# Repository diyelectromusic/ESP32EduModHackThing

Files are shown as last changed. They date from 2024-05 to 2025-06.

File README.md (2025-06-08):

# ESP32EduModHackThing

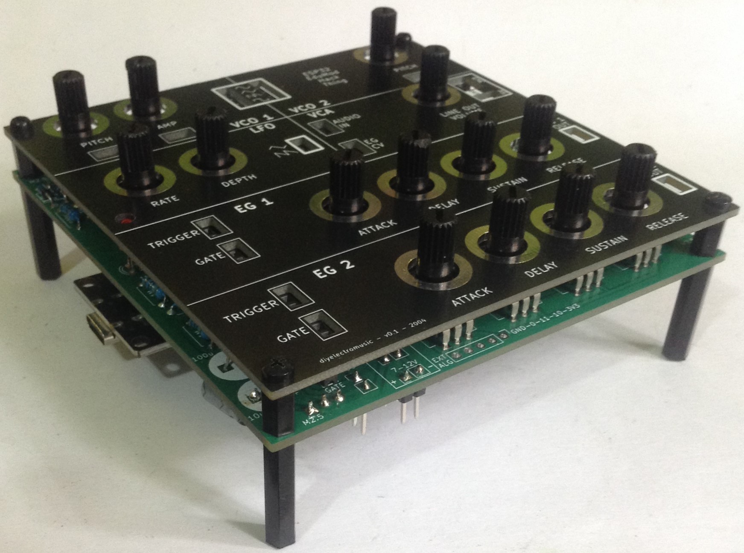
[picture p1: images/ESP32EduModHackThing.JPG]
Photo of the ESP32EduModHackThing


ESP32 based, hacked together modular-synth like thing to help learn the basics of analog synthesis and hook up to breadboards for experimenting with circuits.

* Blog series: https://diyelectromusic.wordpress.com/2024/05/07/educational-diy-synth-thing/

## Getting Started

Once the hardware is ready (see below) here are some links to get started:
* One-sheet Getting Started Guide: [Download Here](Docs/EduModSynthThing-GettingStarted.pdf).
* Some first experiments: https://diyelectromusic.com/2024/06/17/educational-diy-synth-thing-part-5/
* Tutorials: [See Docs area](Docs/)

## Hardware

**Be sure to read the Errata and limitations in the design notes**

Contents of the [Hardware](/Hardware) directory:
* Main PCB - 100x100mm main PCB.
* 24pin DIP Adaptor - small adaptor PCB as a workaround to the errata about the 24-pin DIP socket.
* Front Panel - 100x100mm PCB files that can be used as a front panel.

Note: The above does not include any connections for MIDI, audio, or power.  See the build notes for details.

Additional hardware (optional):
* Connector Panel - 50x100mm PCB files that can be used as an additional accessories/connectors panel.
* 3D Printer STL file - 150x100x35mm approx enclosure for a front panel and connector panel.
* 3D Printer STL file for a low quality tool to help screw in the hex-spacers.
* Alternative Connector Panel - 50x100mm PCB files for accessories/connectors including a JST SH 4-way header for power and MIDI compatible with my Raspberry Pi Pico Touch Keyboard.
* JST SH 4-pin breakout board - breakout board for use with the alternative connecor panel.

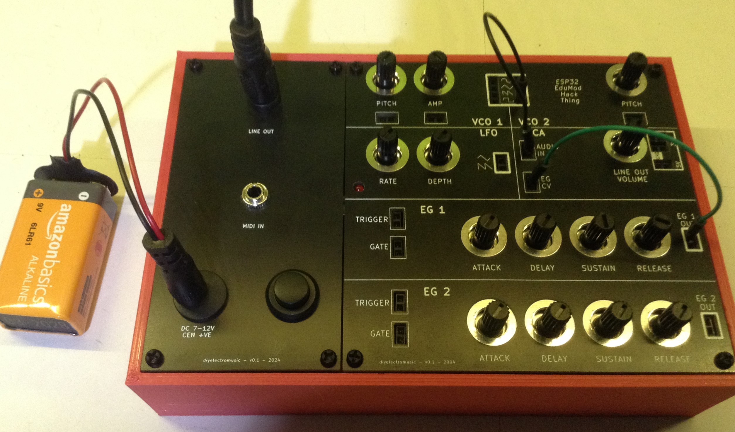
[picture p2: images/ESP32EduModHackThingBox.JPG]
Photo of the ESP32EduModHackThing in its box


Main PCB:
* PCB Design Notes: https://diyelectromusic.wordpress.com/2024/05/07/esp32-wroom-educational-modular-synth-thing-pcb-design/
* PCB Build and Test Notes: https://diyelectromusic.wordpress.com/2024/05/19/esp32-wroom-educational-modular-synth-thing-pcb-design-build-guide/

## Code Directories

* HardwareTestCode - contains a series of sketches that can be used to test specific elements of the board.
* Firmware - contains the current release of the core firmware to perform all the functionss as described in the blog series.

## License, Use, Feedback, Contributions

Released under a MIT license.  No fitness for any purpose suggested or implied.  Use at your own risk.  I am not an electronics person - I'm just messing around.

**Do not plug this into anything else and certainly not anything expensive or wanted.**

Contributions are not being accepted.  This is just a repository for the design, but suggestions and conversations about it welcome on my blog or via social media.

Kevin

_All code and designs Copyright (c) Kevin (diyelectromusic)_

There is no permission, direct or implied, for the contents of this repository to be used for the training of AI systems.

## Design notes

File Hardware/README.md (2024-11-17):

# ESP32EduModHackThing

* Blog series: https://diyelectromusic.wordpress.com/2024/05/07/educational-diy-synth-thing/
* PCB Design Notes: https://diyelectromusic.wordpress.com/2024/05/07/esp32-wroom-educational-modular-synth-thing-pcb-design/
* PCB Build and Test Notes: https://diyelectromusic.wordpress.com/2024/05/19/esp32-wroom-educational-modular-synth-thing-pcb-design-build-guide/

Bill of Materials:
- ESP32 WROOM Educational Modular Synth Thing PCB.
- 24-pin DIP adaptor PCB (see note on footprint error below).
- ESP32 WROOM DevKit.
- 1 x CD4067B 24-pin DIP 16-way analog multiplexer (see note below on footprint error!).
- 1x H11L1 6-pin DIP opto-isolator.
- 1x TDA7052A 8-pin DIP BTL audio amplifier with DC volume control.
- 1x L7805 TO-220 5V voltage regulator.
- Resistors: 1 x 220R, 11 x 470R, 5 x 1K, 4 x 10K, 5 x 100K, 3 x 680K, 6 x 1M, 1 x 2M
- Variable Resistors: 13 x 10K linear (PCB Mount: RK09 footprint), 1 x 100K linear (PCB Mount: RK09 footprint)
- 4 x 2N3904 NPN transistors
- 1 x BC557 PNP transistor
- 5 x 1N4148 signal diodes
- 6 x BAT43 Schottky diode
- 1 x 3mm LED
- Ceramic Capacitors: 10 x 68 nF, 7 x 100nF
- Electrolytic Capacitors: 2 x 1uF, 2 x 10uF, 1 x 100uF
- 15 x 2-way pin header sockets.
- 2 x 4-way pin header sockets.
- Jumper header pins.
- 2 x 15-way pin header sockets.
- Optional: 24-pin DIP socket (see note below on footprint error!).
- Optional: 8-pin DIP socket.
- Optional: 6-pin DIP socket.

Errata:
- The 24-pin DIP footprint is incorrect and requires an adaptor board.
- There is no board space to allow the two power supply electrolytics to bend over the PCB.
- The footprint for the 2N3904 transistors is too small for easy soldering.
- Using GPIO 2, 4, 15 as analog input values causes issues - see design notes for details.
- The panel uses "DELAY" rather than "DECAY" in the lables for the ADSR...

This repository also contains:
* 24-pin DIP narrow to wide adaptor.
* Front panel design.
* Connector panel design.
* Alternative connector panel "V2" design (includes a JST SH breakout).
* JST SH 4-pin breakout board.
* STL file for a 3D Printed box for both panels.
* STL file for a 3D Printed tool to help screw in spacers.

If you like what you see, you can buy me a Ko-Fi - https://ko-fi.com/diyelectromusic

#  A Word of Caution!

Please note - I consider myself a novice at pcb design!

**Don't spend your own time and resources on any of these designs without knowing what you are doing.  They are not "off the shelf products" ready to go!**

Do not use this with expensive computer, audio, music or electronic equipment, it is for hobby use only.  For more details, see https://diyelectromusic.wordpress.com/pcbs/

# License

All information is provided AS IS with no implied fit for purpose as detailed in the included MIT License.

All content and code (c) diyelectromusic (Kevin)

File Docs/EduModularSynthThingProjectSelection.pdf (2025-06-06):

# The Educational DIY Synth Thing

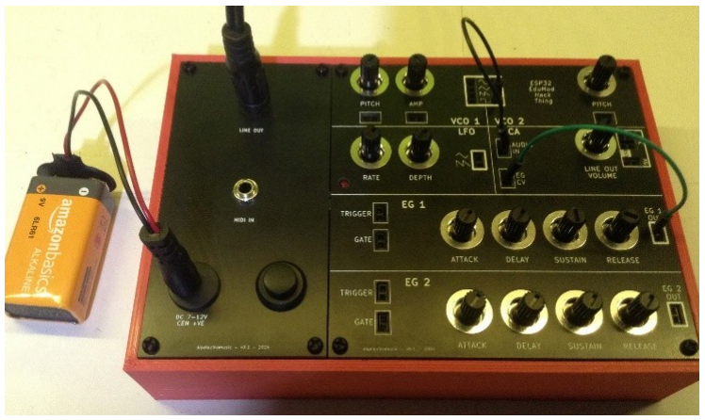
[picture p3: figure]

### Project Selection – v0.1 – June 2025 © diyelectromusic 2025

https://diyelectromusic.com/2024/05/07/educational-diy-synth-thing/ (https://diyelectromusic.com/2024/05/07/educational-diy-synth-thing/)

# 1. Basic Oscillator (VCO) Output

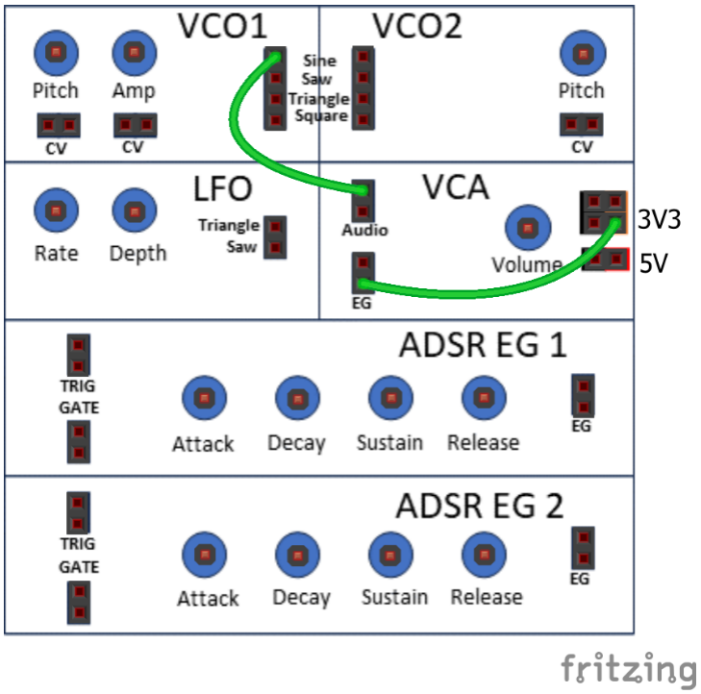
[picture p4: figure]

- VCA EG fixed at 3V3.
- Turn up VCA Volume.

## - Experiment with:

- VCO1 Amp.
- VCO1 Pitch.

## - What are the highest and lowest frequencies?

# 2. Dual Oscillator Output

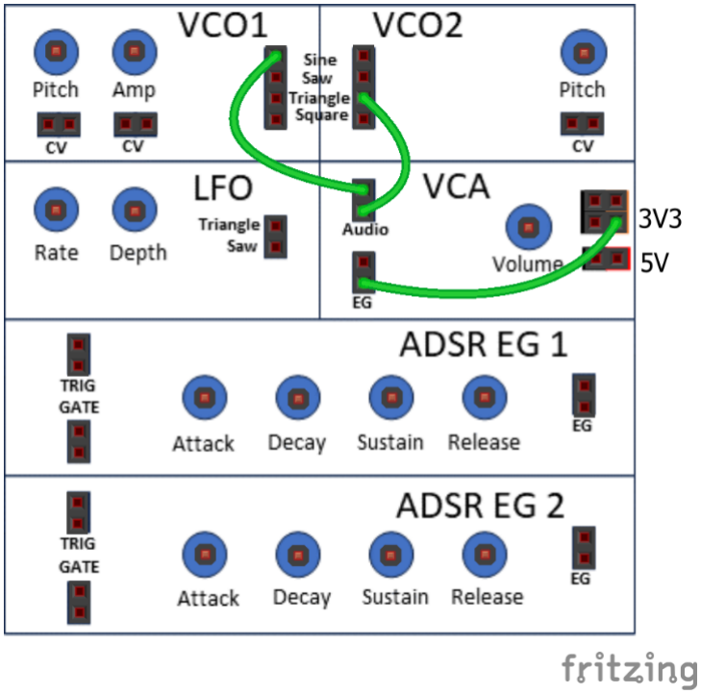
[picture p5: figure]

## - Change:

- VCO1 and VCO2 Pitch.
- VCO1 Amp.
- VCO1 and VCO2 Waveforms.

## - Experiments:

- Tune to same pitch.
- Detune one slightly.
- Tune to 1 octave apart.
- Tune to 2 octaves.
- Find other intervals.

# 3. Dual VCO+LFO Pitch Modulation

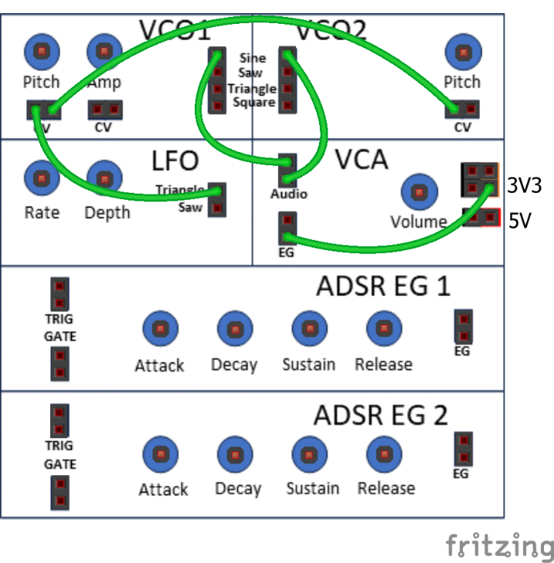
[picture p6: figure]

- Links VCO1 and VCO2 CVs.

## - Turn LFO off and tune VCOs to 1

octave.
- Try LFO Rate and Depth.
- Try LFO waveforms.

## - Connect one LFO waveform to

VCO1 and one to VCO2.

# 4. ADSR Envelope Generator for Amplitude and Pitch

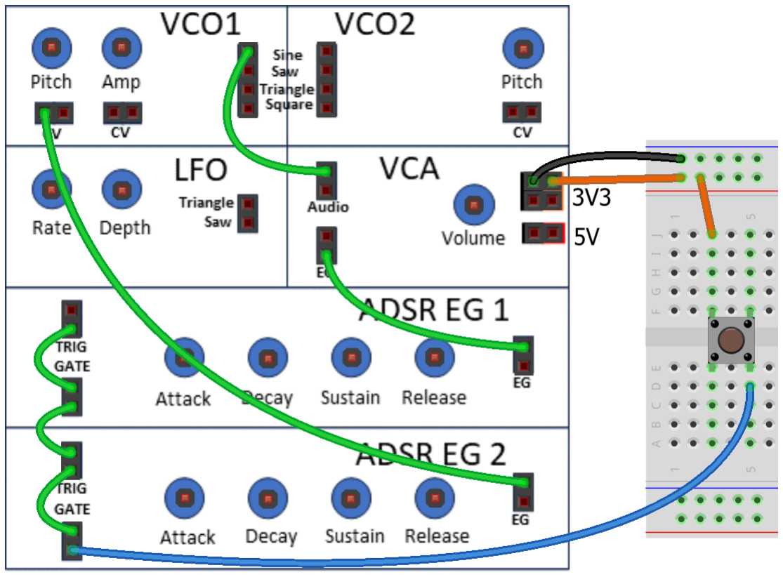
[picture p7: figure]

- EG1 back to controlling VCA.
- EG2 now controlling VCO Pitch.

## - Try different A, D, S, R settings for

both amplitude and pitch.

# 5. ADSR Envelope Generator – Dual Pitch

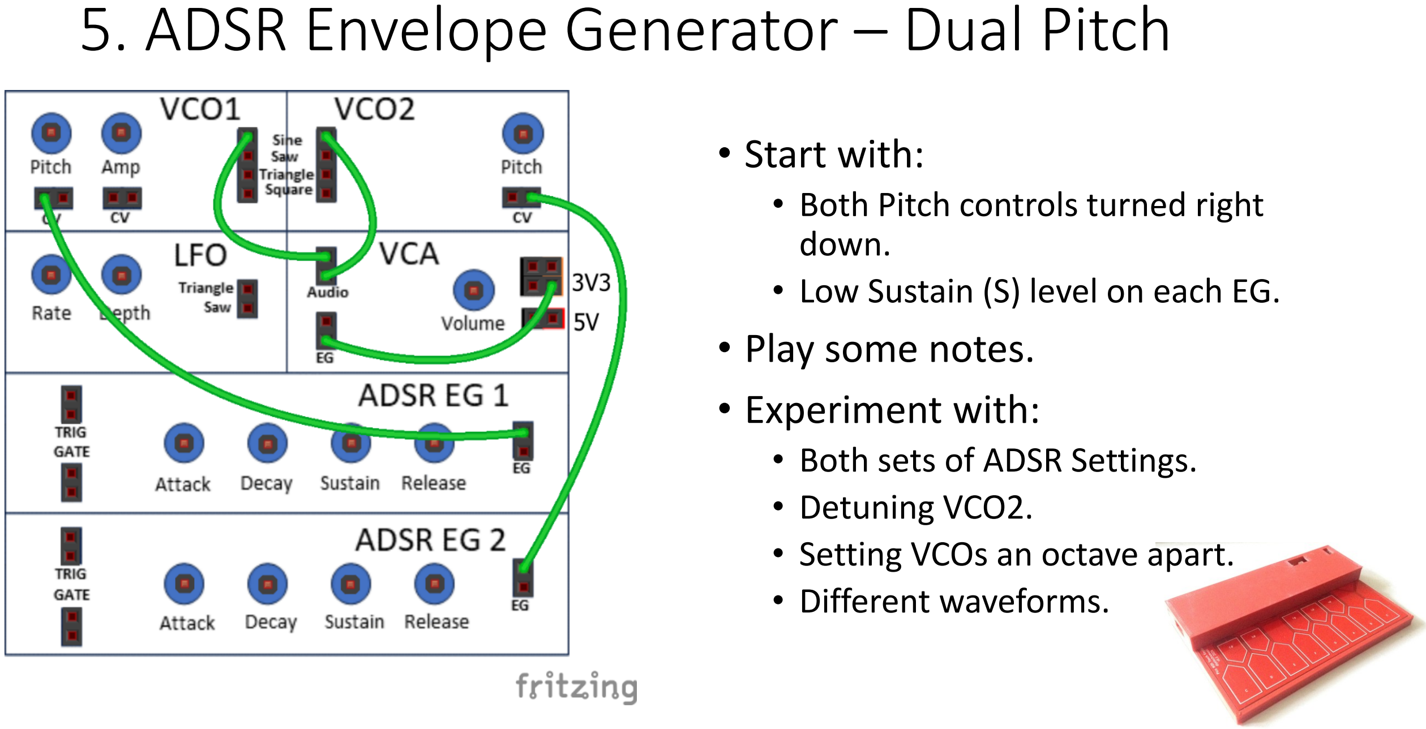
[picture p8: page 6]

## - Start with:

## - Both Pitch controls turned right

down.
- Low Sustain (S) level on each EG.
- Play some notes.

## - Experiment with:

- Both sets of ADSR Settings.
- Detuning VCO2.
- Setting VCOs an octave apart.
- Different waveforms.

# 6. Dual Pitch Sequence

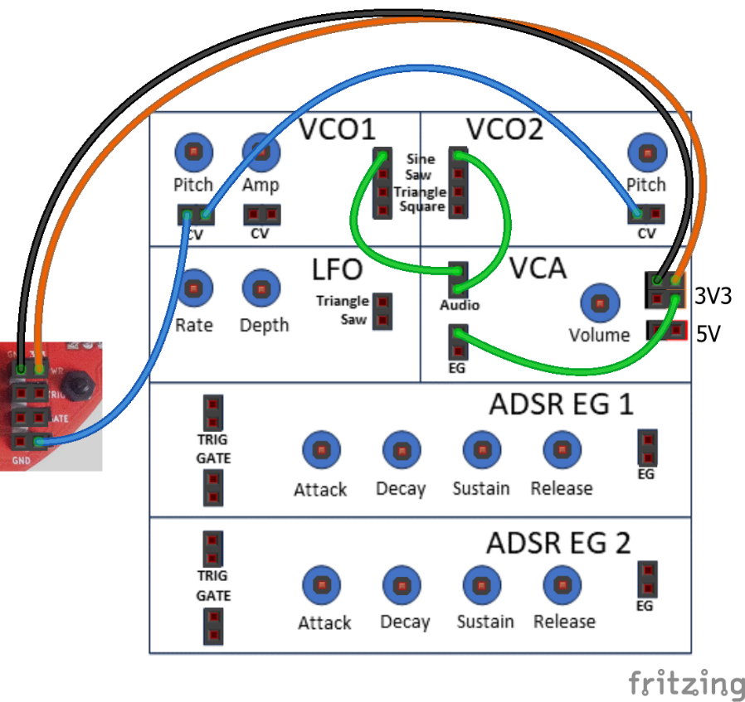
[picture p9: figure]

- Both VCOs connected.

## - Start with:

- VCO Pitch controls turned right down.
- VCO1 Amp and VCA Volume right up.
- Baby 8 steps fully clockwise (8 steps).
- Baby 8 Run/Stop -> Run (to the right).

## - Experiment with:

- Detune VCO2.
- Different Waveforms.
- Different Pitch controls.
- Adjust the sequence.

# 7. Dual Oscillators and Oscilloscope

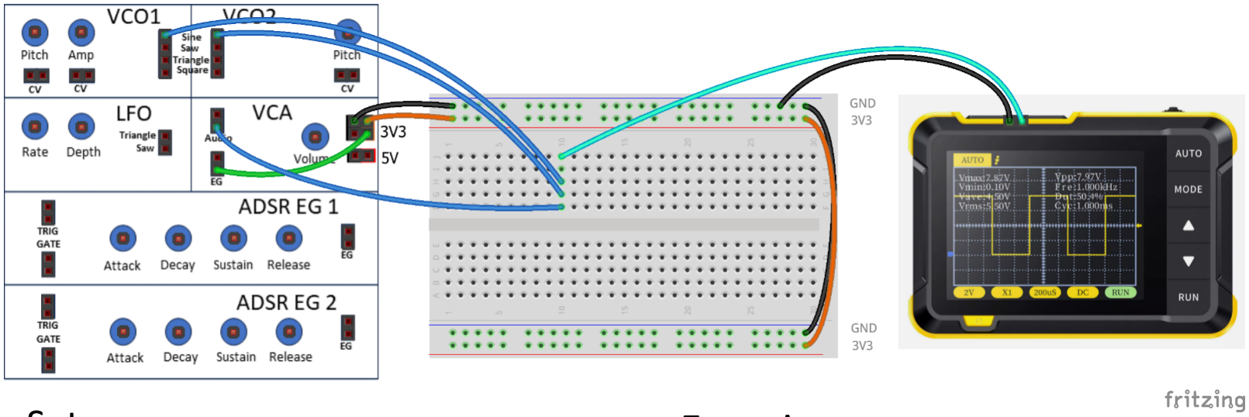
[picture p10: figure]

## Setup:

- VCA Amp turned fully clockwise.
- VCO1 Amp fully anticlockwise (off).
- VCO1 and VCO2 Pitch half-way.
- Use both Sine outputs.

## Experiment:

- Slowly increase VCO1 Amp.
- Tune both VCOs to same Pitch.
- Watch how the waveform slowly changes.

# 8. LED Indicator

## - Experiment with:

## - LFO Rate - LFO Depth - LFO Waveform

## - Contrast fast rate with

very slow rate.

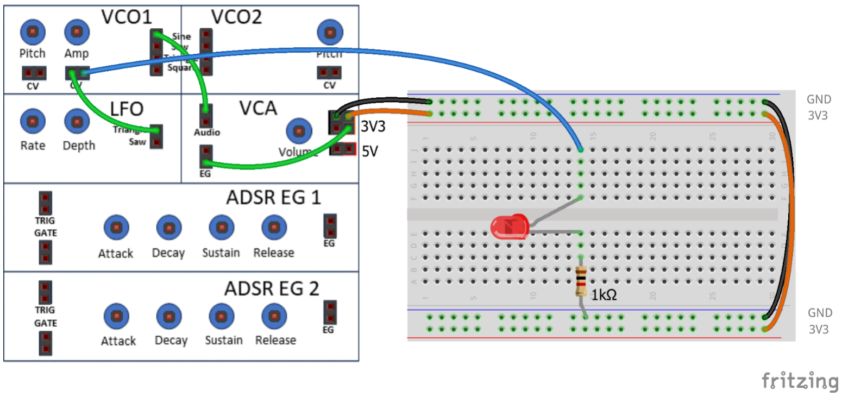
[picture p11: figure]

## Setup

- VCO1 Amp fully anti-clockwise (“off”).
- VCO1 Pitch half-way.
- LFO Depth half-way.
- LFO Rate fully anti-clockwise (“slow”).

# 9. Potentiometer Control

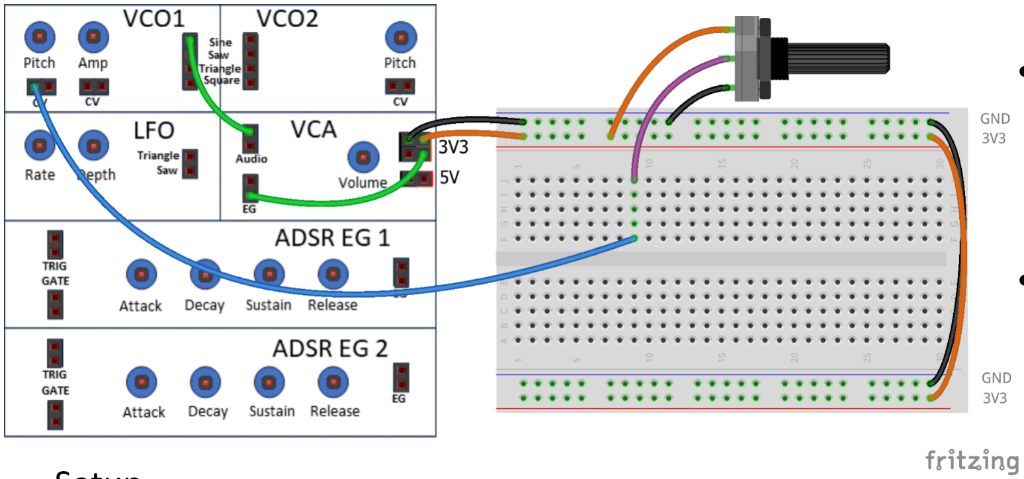
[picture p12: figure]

## - Experiment with:

## - VCO1 Pitch - Pot Control

## - Notice how the two add to each other…

## Setup

- Pot between 3V3 and GND.
- VCO1 Amp and VCA Vol fully clockwise.

# 10. Light Dependant Resistor Control

## - Move hand over the

LDR.

## - Experiment with different positions from fully covered to

fully open.

## - This simulates an instrument called a

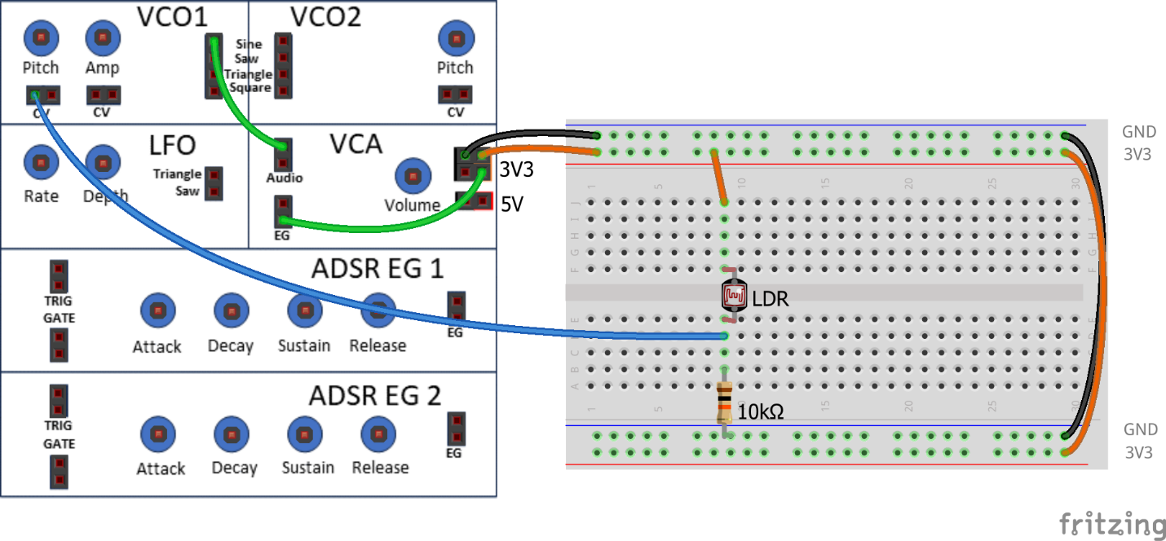
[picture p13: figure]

Setup | “Theremin”.
- VCO1 Pitch half-way.
- VCO1 Amp and VCA Vol fully clockwise.

# 11. Force Sensitive Resistor Control

## - Apply Pressure to the FSR…

## - Now acts as a “pitch bend” for the Synth

Thing.

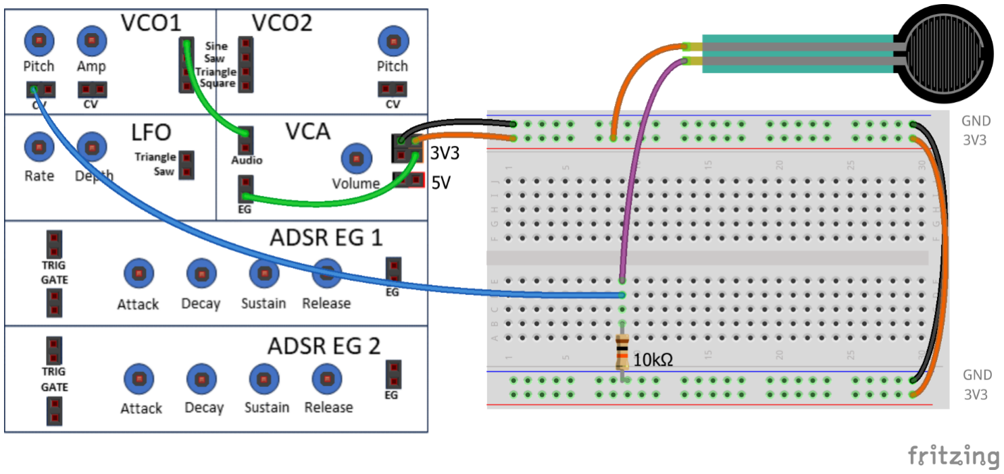
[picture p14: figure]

## Setup

- FSR between 3V3 and via 10KΩ resistor to GND.
- VCO1 Amp and VCA Vol fully clockwise.
- VCO1 Pitch half-way.

# 12. “Thumb” Joystick Control

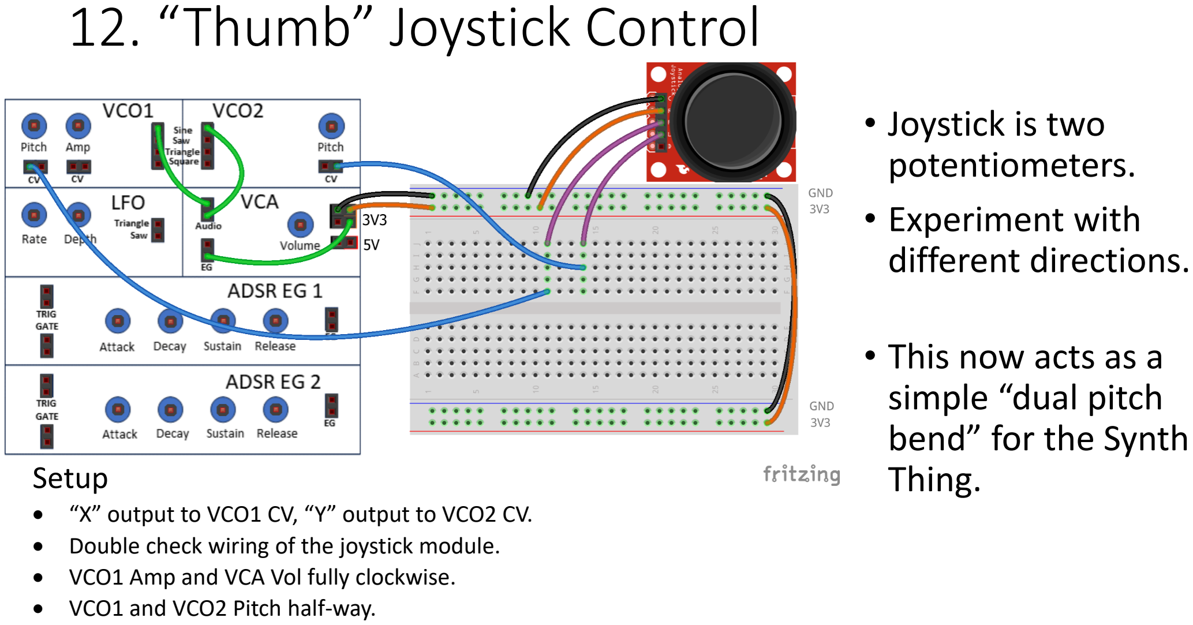
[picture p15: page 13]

## - Joystick is two

potentiometers.

## - Experiment with

different directions.

## - This now acts as a simple “dual pitch bend” for the Synth

Setup | Thing.
- “X” output to VCO1 CV, “Y” output to VCO2 CV.
- Double check wiring of the joystick module.
- VCO1 Amp and VCA Vol fully clockwise.
- VCO1 and VCO2 Pitch half-way.

# 13. Adjustable Low-pass Filter

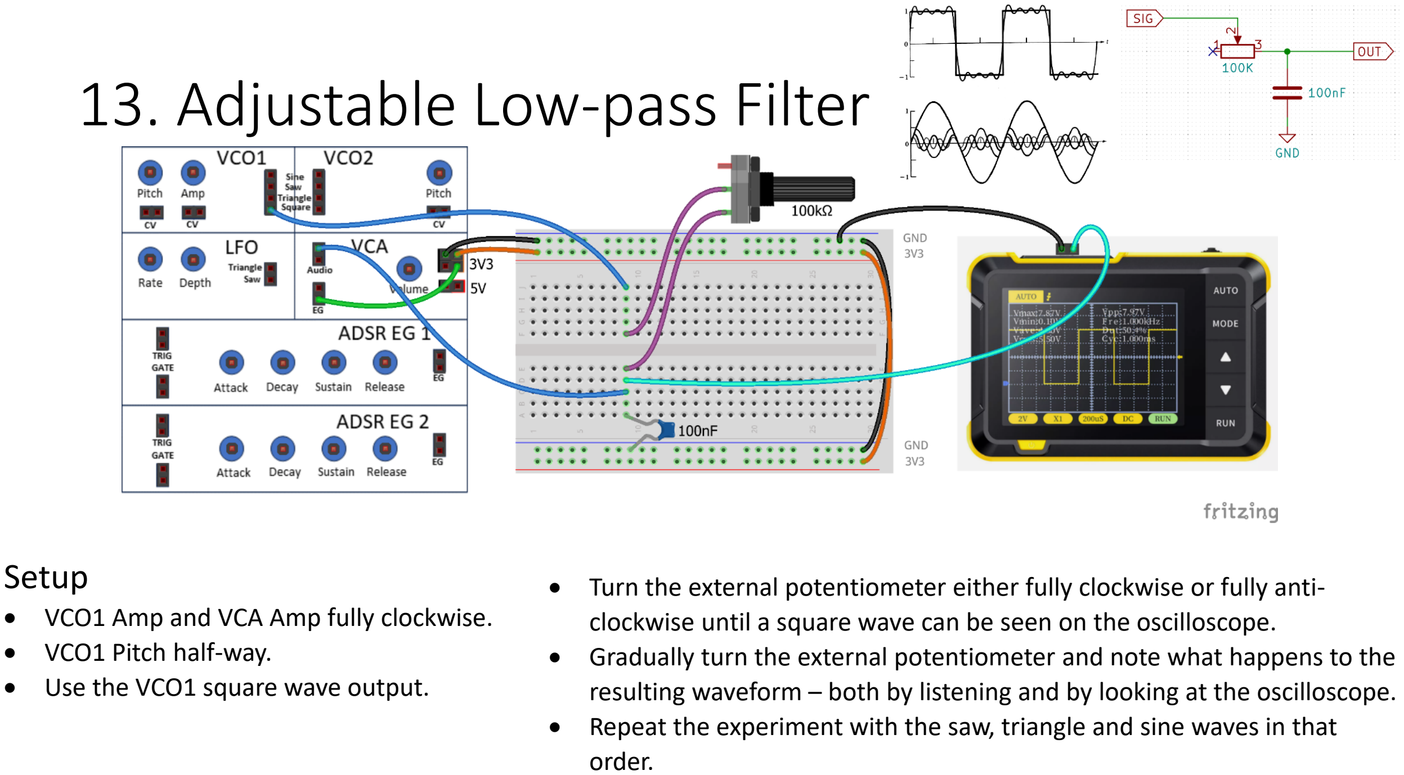
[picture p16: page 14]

## Setup

- VCO1 Amp and VCA Amp fully clockwise.
- VCO1 Pitch half-way.
- Use the VCO1 square wave output.
- Turn the external potentiometer either fully clockwise or fully anticlockwise until a square wave can be seen on the oscilloscope.
- Gradually turn the external potentiometer and note what happens to the resulting waveform – both by listening and by looking at the oscilloscope.
- Repeat the experiment with the saw, triangle and sine waves in that order.

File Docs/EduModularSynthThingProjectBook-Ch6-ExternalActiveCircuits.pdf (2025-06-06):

Page 1 – Issue 0.1 – May 2025 - © diyelectromusic 2025 - https://diyelectromusic.com/2024/05/07/educational-diy-synth-thing/

## The Educational DIY Synth Thing

## External Active Circuit Projects

### Introduction

This carries on from the previous chapters and assumes that one has a working Synth Thing and has worked through all of the starter projects.

There are five sections in this chapter covering the following:

- Basic Principles and Connections

In each case once general amplification and power are required as used previously.

### Core Components Required

The following basic additional components are required to perform all the experiments in this chapter:

- Solderless breadboard – ideally a “half+” type.
- Optional: Oscilloscope, adaptors and probes (see previous chapter on oscilloscope use).
- CD4093 Quad Schmitt Trigger NAND Gate
- 74LS175 Quad D-Type flip flop
- Range of additional passive components

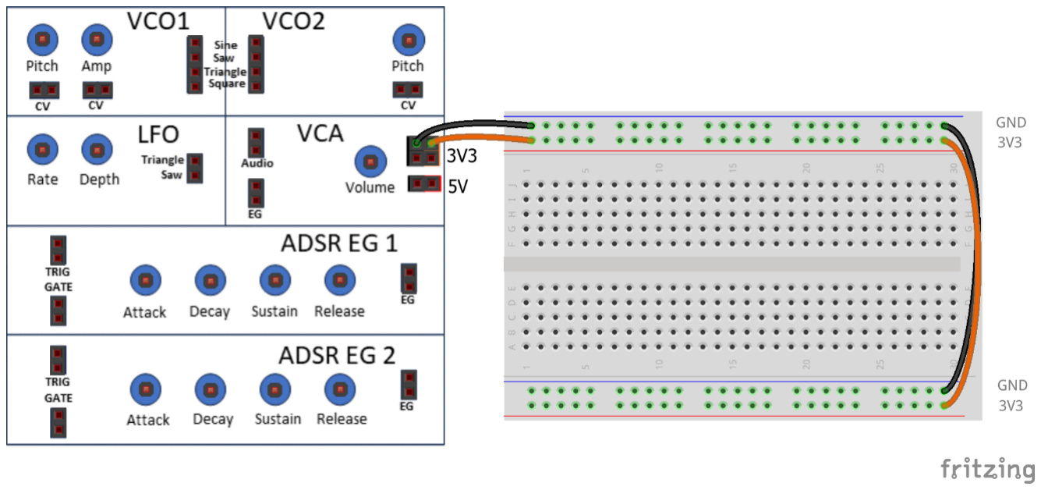
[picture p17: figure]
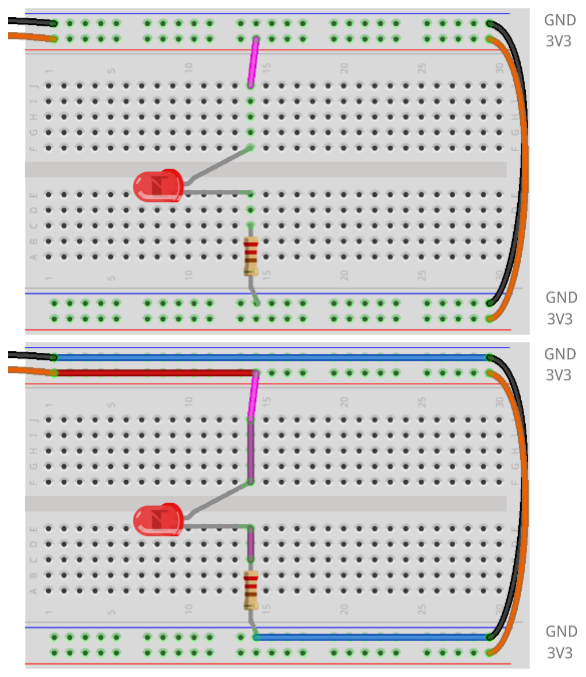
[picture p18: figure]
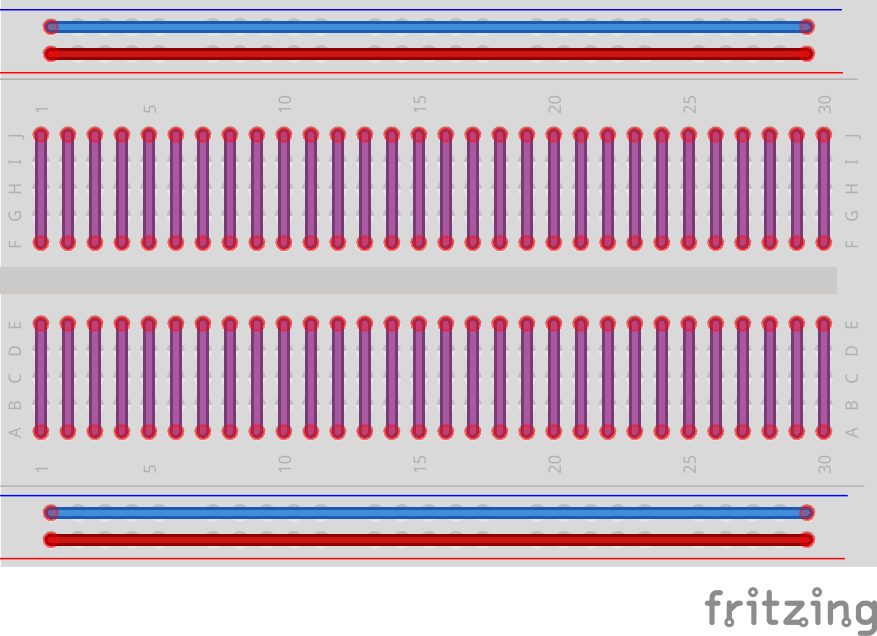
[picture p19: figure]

Page 2 – Issue 0.1 – May 2025 - © diyelectromusic 2025 - https://diyelectromusic.com/2024/05/07/educational-diy-synth-thing/

### Basic Principles and Connections

Repeating the notes from the previous section, this again shows how to connect a solderless breadboard ready to start some experiments.

The power should ideally be kept within the 0-3V3 range, so it is recommended that, unless it is stated otherwise, the solderless breadboard is connected to GND and 3V3 as shown below.

It is also recommended that the blue row is used to signify GND and the red row is used for 3V3.

The holes in a solderless breadboard are internally connected as show below, making joining circuits relatively straightforward. Anything plugged into one of the holes in a row or column is automatically connected to anything plugged into any of the other holes in the same row or column.

The top (right) diagram shows how an LED could be wired to 3V3 and GND. The bottom (right) diagram shows the path of the completed circuit through the solderless breadboard.

Summary of the colours used in these project diagrams:

- Green – internal connections between patch points on the Synth Thing.
- Blue – external connections between the Synth Thing and the breadboard.
- Black – GND connections.
- Orange – 3V3 connections.
- Red – 5V connections.
- Other Colours – other connections on the breadboard as required.

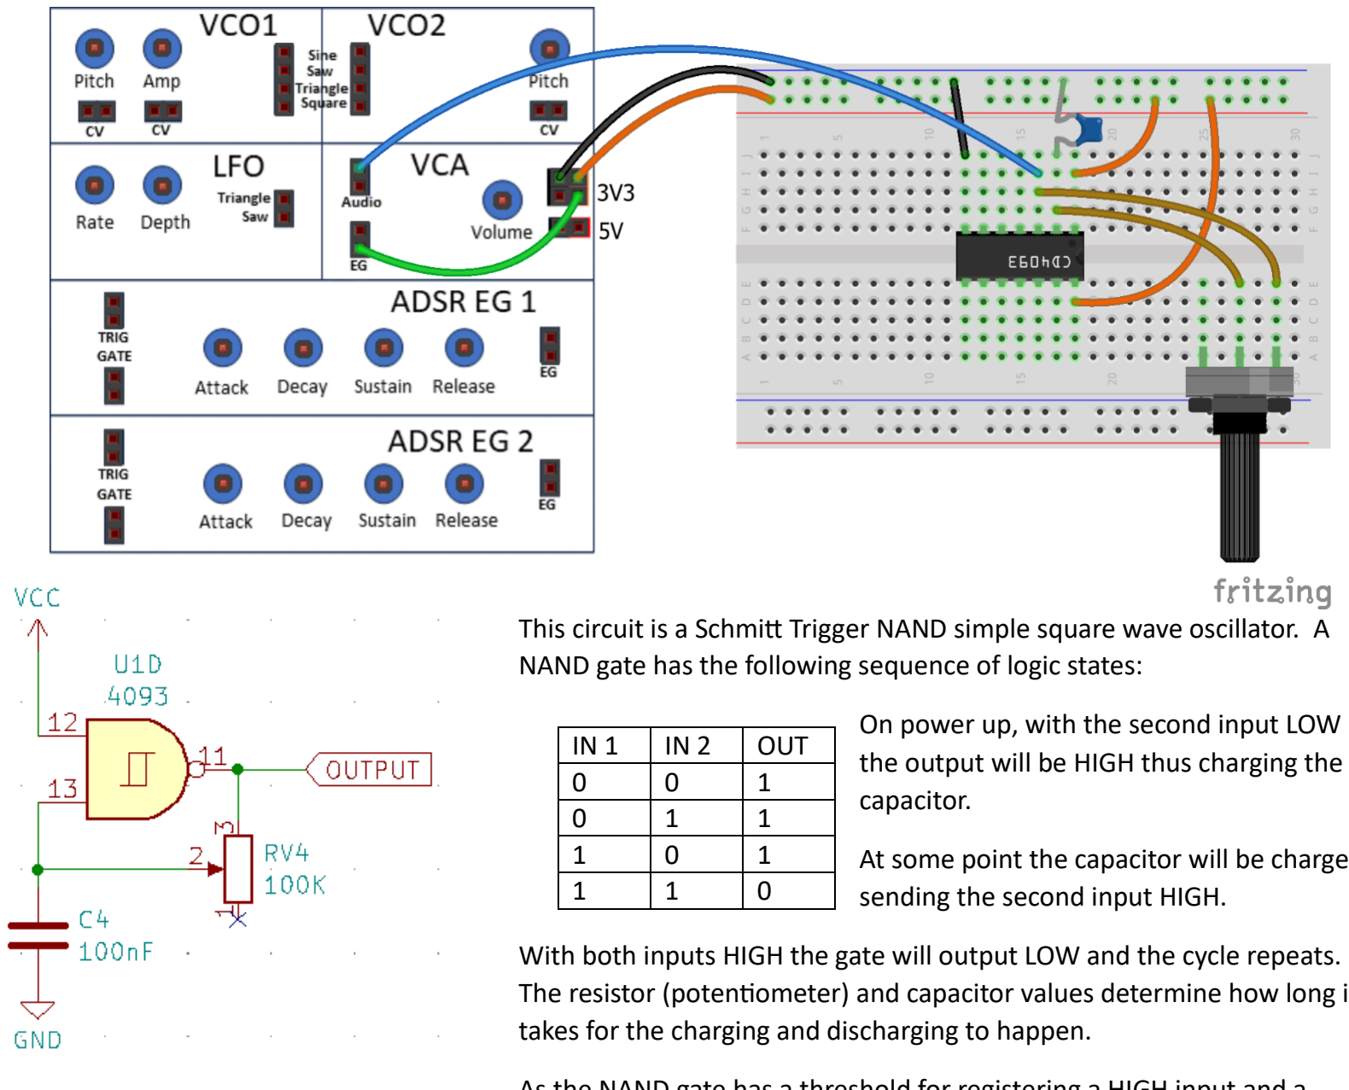
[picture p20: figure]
On power up, with the second input LOW; capacitor.; sending the second input HIGH.; OUT
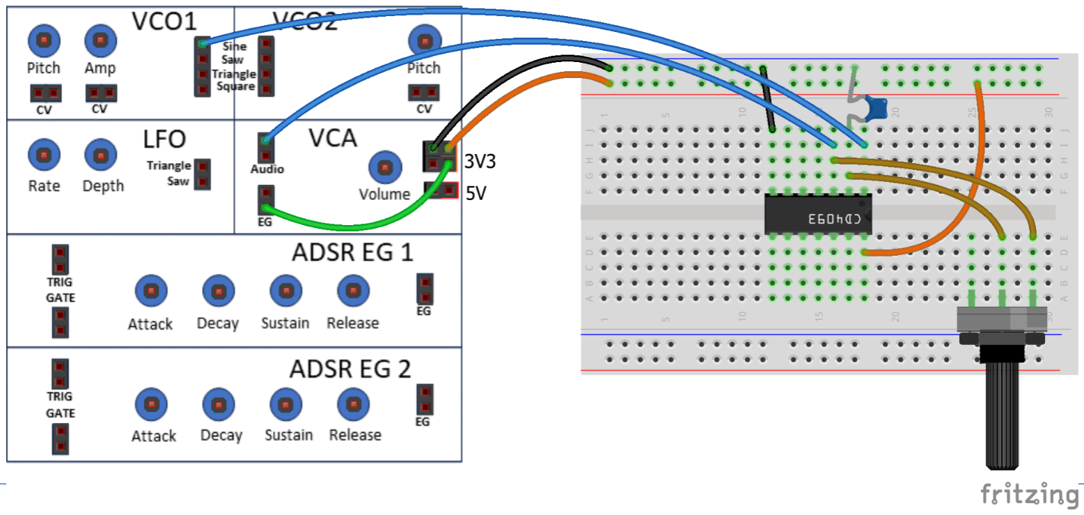
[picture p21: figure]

Page 3 – Issue 0.1 – May 2025 - © diyelectromusic 2025 - https://diyelectromusic.com/2024/05/07/educational-diy-synth-thing/

## Oscillators

## 1. NAND Schmitt Trigger Oscillator

This circuit is a Schmitt Trigger NAND simple square wave oscillator. A NAND gate has the following sequence of logic states:

the output will be HIGH thus charging the

At some point the capacitor will be charged

With both inputs HIGH the gate will output LOW and the cycle repeats. The resistor (potentiometer) and capacitor values determine how long it takes for the charging and discharging to happen.

As the NAND gate has a threshold for registering a HIGH input and a specified HIGH or LOW output, this creates a square wave.

For a further experiment, replace the fixed HIGH signal into the NAND gate with the output from one of the VCOs as shown below.

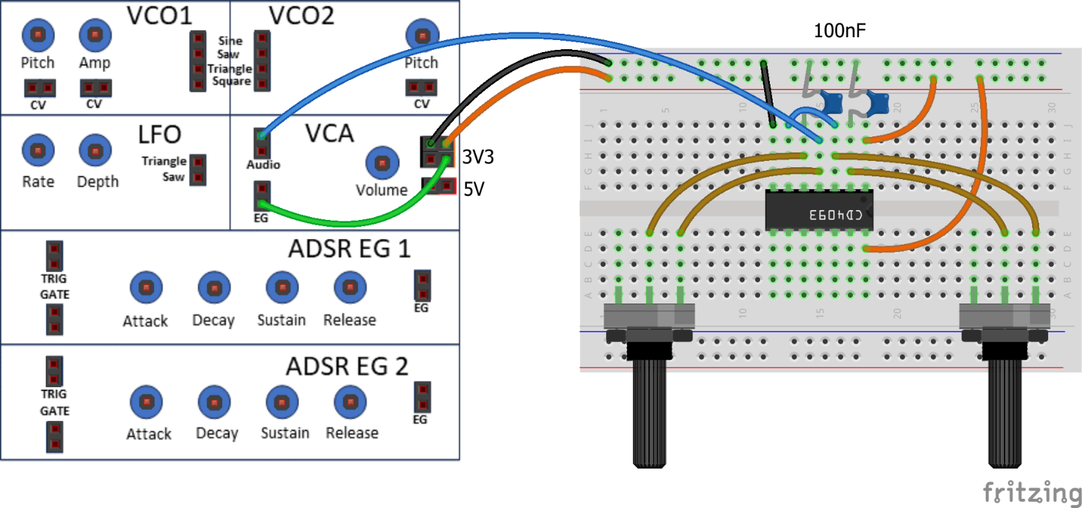
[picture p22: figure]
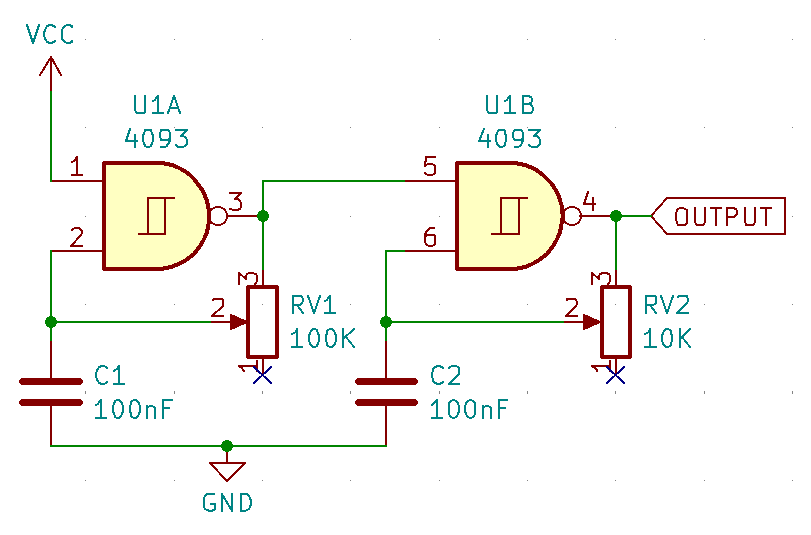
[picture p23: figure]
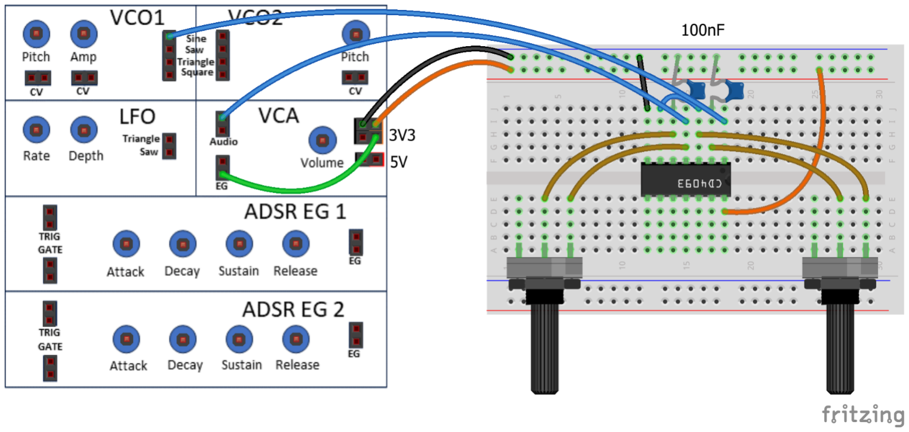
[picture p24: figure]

Page 4 – Issue 0.1 – May 2025 - © diyelectromusic 2025 - https://diyelectromusic.com/2024/05/07/educational-diy-synth-thing/

### 2. NAND Schmitt Trigger Dual Oscillator

This circuit uses two Schmitt trigger NAND gates from a 4093 quad NAND IC.

Each NAND gate is configured as a simple square wave oscillator with one input via a capacitor to GND, the other to a voltage source, and with feedback controlled by a potentiometer.

The first oscillator starts with a constant VCC. The second oscillator is fed from the output of the first leading to some fascinating dualoscillator effects.

Once again replace the fixed input to the NAND gates with the output from VCO and now experiment with all three potentiometers and different waveforms. For an additional experiment use the output of the LFO instead.

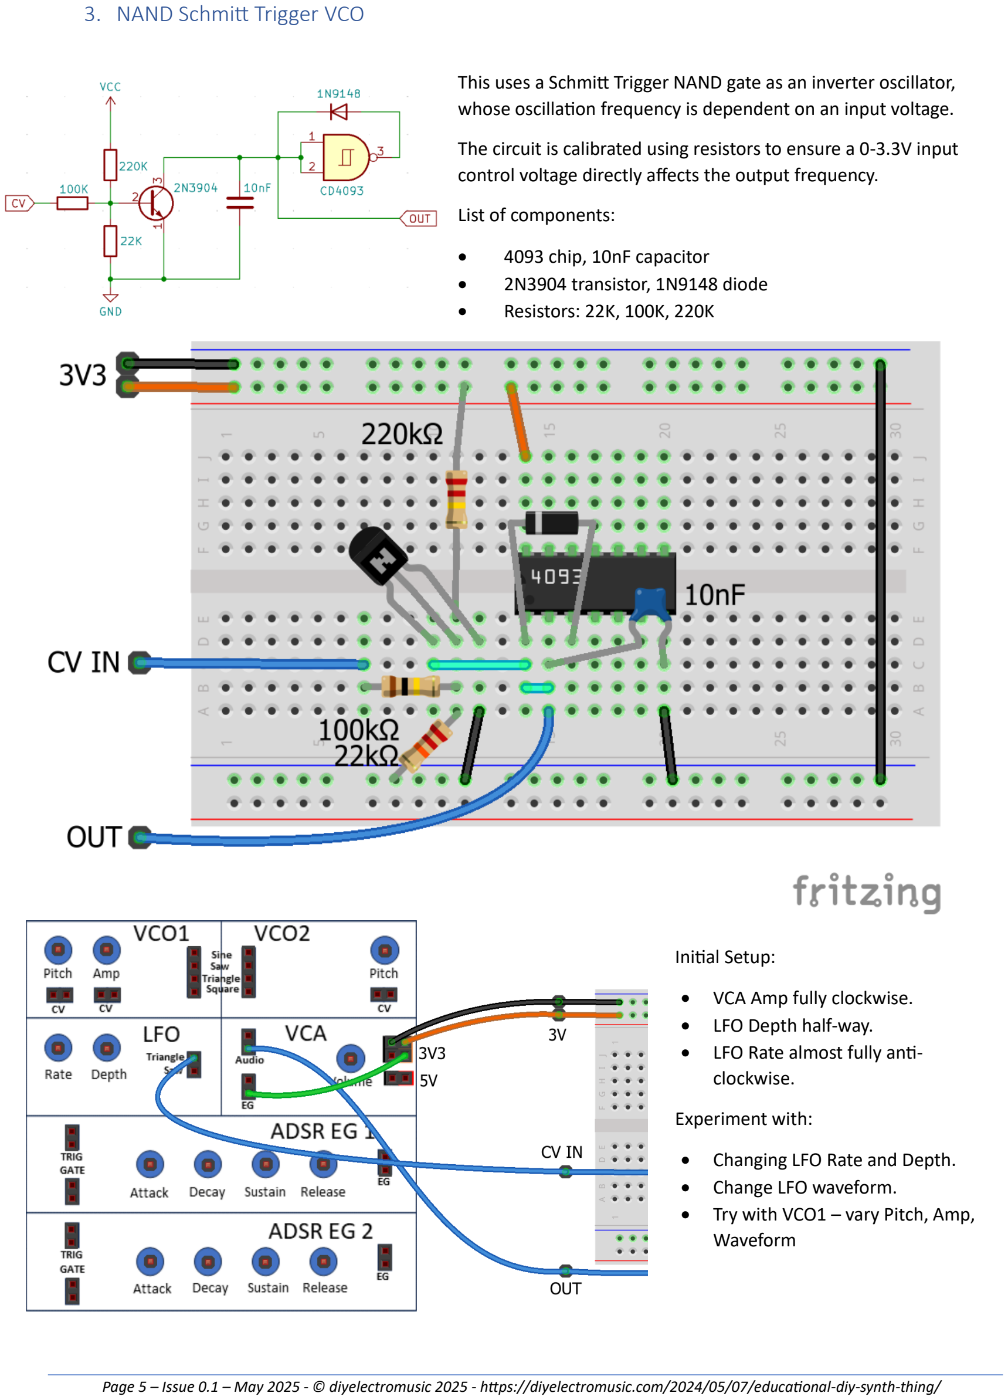
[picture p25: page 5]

Page 5 – Issue 0.1 – May 2025 - © diyelectromusic 2025 - https://diyelectromusic.com/2024/05/07/educational-diy-synth-thing/

### 3. NAND Schmitt Trigger VCO

This uses a Schmitt Trigger NAND gate as an inverter oscillator, whose oscillation frequency is dependent on an input voltage.

The circuit is calibrated using resistors to ensure a 0-3.3V input control voltage directly affects the output frequency.

List of components:

- 4093 chip, 10nF capacitor
- 2N3904 transistor, 1N9148 diode
- Resistors: 22K, 100K, 220K

Initial Setup:

- VCA Amp fully clockwise.
- LFO Depth half-way.
- LFO Rate almost fully anticlockwise.

Experiment with:

- Changing LFO Rate and Depth.
- Change LFO waveform.
- Try with VCO1 – vary Pitch, Amp, Waveform

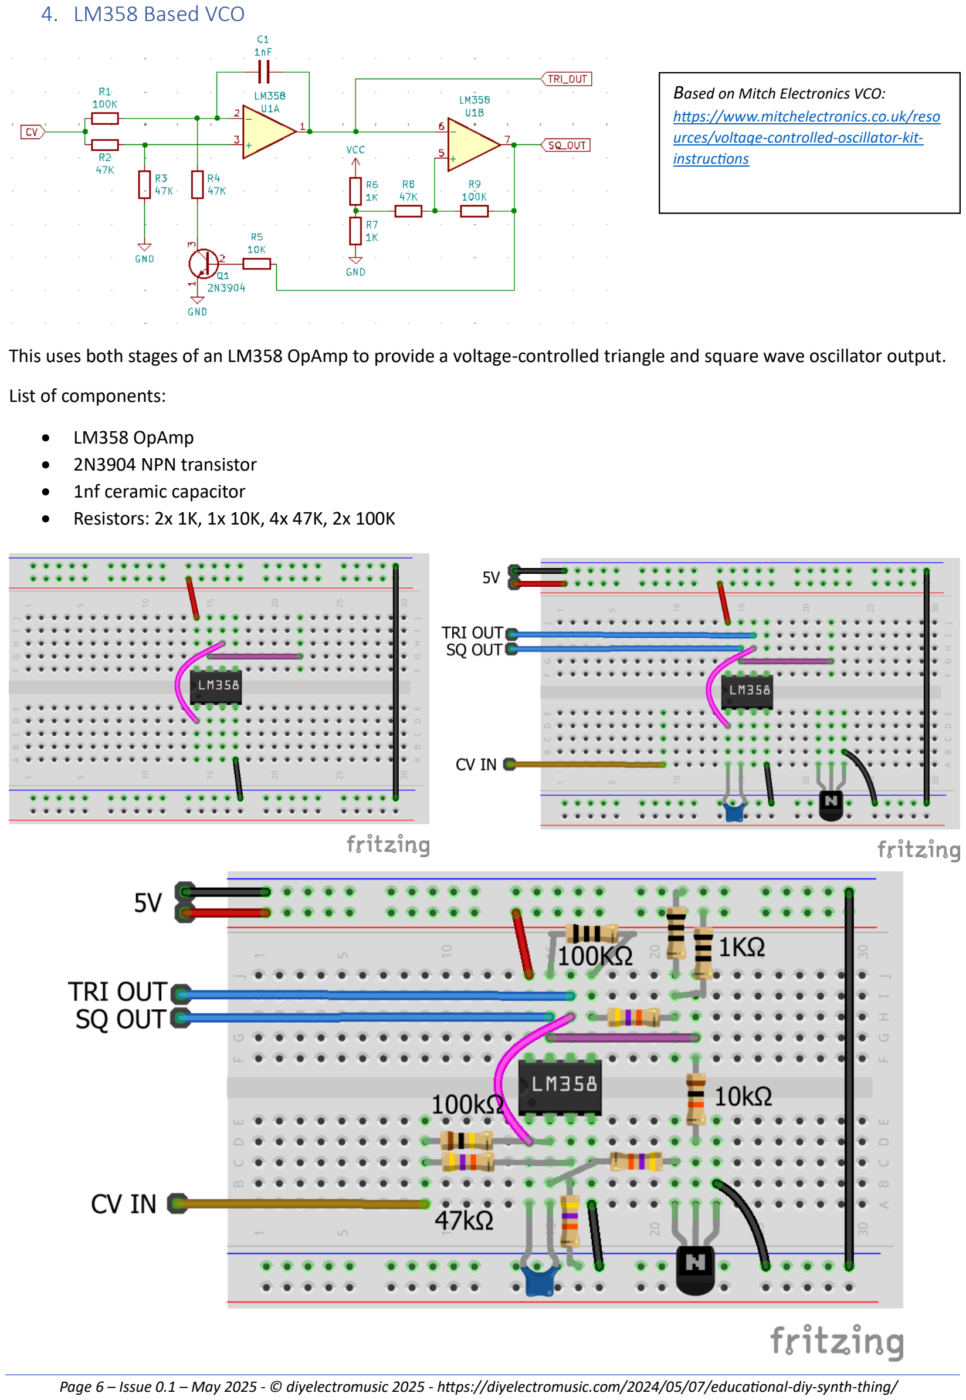
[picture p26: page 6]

Page 6 – Issue 0.1 – May 2025 - © diyelectromusic 2025 - https://diyelectromusic.com/2024/05/07/educational-diy-synth-thing/

### 4. LM358 Based VCO

This uses both stages of an LM358 OpAmp to provide a voltage-controlled triangle and square wave oscillator output.

List of components:

- LM358 OpAmp
- 2N3904 NPN transistor
- 1nf ceramic capacitor
- Resistors: 2x 1K, 1x 10K, 4x 47K, 2x 100K

Based on Mitch Electronics VCO: https://www.mitchelectronics.co.uk/resources/voltage-controlled-oscillator-kitinstructions (https://www.mitchelectronics.co.uk/resources/voltage-controlled-oscillator-kit-instructions)


Page 7 – Issue 0.1 – May 2025 - © diyelectromusic 2025 - https://diyelectromusic.com/2024/05/07/educational-diy-synth-thing/

Connection to the Synth Thing requires GND/5V. There is one input to the circuit FROM the synth thing – the CV IN; and one of the TRI or SQ OUT can be connect TO the synth thing VCA audio input.

Start with the VCA volume fully clockwise (turned up); the LFO depth and rate about half-way.

Use an oscilloscope on GND and AUDIO IN to see the produced waveforms.

Experiment with the following:

- Vary the LFO Rate and Depth and see the effect on the wave form.
- Switch to the Saw output and vary the LFO Rate and Depth.
- Switch from the LFO to the output of VCO1, start with VCO pitch fully anticlockwise and Amp half-way round.
- Vary the VCO1 Pitch.
- Vary the VCO1 Amp.
- Try alternative VCO1 waveforms.


Page 8 – Issue 0.1 – May 2025 - © diyelectromusic 2025 - https://diyelectromusic.com/2024/05/07/educational-diy-synth-thing/

### 5. LS175 Flip Flop Frequency Divider

This uses a “D-type flip flop” as a clock divider to half the frequency of the input signal.

A flip-flop is used to half the frequency of the incoming signal. Then the incoming and halved signals are combined via a simple resistor passive mixer to give a combined output. The halved signal is always a square wave, but the triggering signal can be any waveform, but it may trigger a change of state at different times depending on the thresholds for “high” and “low” that the device has.

Initial Setup:

- VCA volume fully clockwise.
- VCO1 amplitude around half-way.
- VCO1 pitch turned fully anticlockwise.

Experiment:

- Experiment with VCO1 patch, amplitude and waveforms.
- View the output waveform on an oscilloscope and see how the different waveforms combine with the halffrequency square wave produced.

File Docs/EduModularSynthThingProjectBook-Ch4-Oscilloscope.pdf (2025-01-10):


Page 1 – Issue 0.1 – Jan 2025 - © diyelectromusic 2025 - https://diyelectromusic.com/2024/05/07/educational-diy-synth-thing/

## The Educational DIY Synth Thing

## Oscilloscope Use

### Introduction

An oscilloscope is really useful for seeing signals and waveforms, and for audio frequencies even a cheap (sub £30) digital oscilloscope is really useful.

This assumes the use of a DSO152 oscilloscope as shown below. These are available quite cheaply online. But any other oscilloscope should be fine too.

In each case once general amplification and power are required as used previously.

DSO 152 Oscilloscope – available online for around £30.

### Core Components Required

The following basic additional components are required to perform all the experiments in this chapter:

- Solderless breadboard – ideally a “half+” type.
- Oscilloscope, adaptors and probes.
- Jumper and patch wires.
- Amplification, power and audio leads.


Page 2 – Issue 0.1 – Jan 2025 - © diyelectromusic 2025 - https://diyelectromusic.com/2024/05/07/educational-diy-synth-thing/

### Oscilloscope Controls

The basic operation of the oscilloscope is shown below. Note On/Off has to be held for a short while to turn it on. A short press will power it off. There is a USB-C port for charging the internal battery.

There is a left/right/push control at the top which selects various items on the display which can then be adjusted using the up/down buttons.

The other buttons switch between various modes of operation as shown above.

The adjustable parameters from the menu selector are shown below.

Although in many cases it will be sufficient to press “AUTO” and let the oscilloscope work it out for itself.


Page 3 – Issue 0.1 – Jan 2025 - © diyelectromusic 2025 - https://diyelectromusic.com/2024/05/07/educational-diy-synth-thing/

Here is a copy of the basic control “cheat sheet”

### Probes and Connections

The oscilloscope comes with a basic crocodile clip lead and USB-C to USB-A power cable. For a little extra cost at time of purchase, a probe set can also be included.

Other items that will be really useful include: RCA (phono) to BNC adaptor; RCA (phono) to 3.5mm stereo TRS jack adaptor; twin RCA (phono) to 3.5mm stereo TRS jack lead.

But for many experiments simply using the crocodile clips to connect to jumper/patch wires will be sufficient.


Page 4 – Issue 0.1 – Jan 2025 - © diyelectromusic 2025 - https://diyelectromusic.com/2024/05/07/educational-diy-synth-thing/

## Oscilloscope Use with a Breadboard

### 1. Oscilloscope and breadboard

This project shows how using a solderless breadboard can make connecting the oscilloscope a bit easier.

Whenever there isn’t a spare connector for the oscilloscope, signals can be brought off the Synth Thing to the solderless breadboard and joined together to allow a spare connector for the scope.

Notice that the oscilloscope is connected to the breadboard GND which saves using one of the few connections on the Synth Thing itself.

The oscilloscope GND can remain connected whilst the “active” wire can be used as a probe to move to different locations on the breadboard or Synth Thing to explore what is happening.

With a basic Sinewave signal, start with the controls as follows:

- VCO1 Amp and VCA Amp turned fully clockwise.
- VCO1 Pitch half-way.
- Press “AUTO” on the oscilloscope.

This should show the output sine waveform on the display.

Switch between the four different waveform outputs for VCO1 and observe each on the oscilloscope.

Then switch back to the Sine wave.

### 2. Oscilloscope Detailed Parameters

Continuing with the same circuit as the firs experiment, we can now look a the Oscilloscopes main controls.

If there is no writing already on the display, push and hold “RUN” until the writing appears.

- Change the VCO1 Pitch and watch how the frequency changes.
- Change the VCO1 Amp and watch how the Vmax and Vpp changes.

Vpp means the “peak to peak” voltage the difference between the lowest and highest voltages shown on the display. The internal audio signals of the Synth Thing will be 0 to 3.3V.


Page 5 – Issue 0.1 – Jan 2025 - © diyelectromusic 2025 - https://diyelectromusic.com/2024/05/07/educational-diy-synth-thing/

### 3. Oscilloscope Horizontal Scale

The menu selector at the top of the scope can be used to highlight the middle yellow oval at the bottom on the display. This is the oscilloscopes time-base measure and will set the horizontal scale.

There will often be a number in “mS” units, corresponding to the number of milli-seconds (1000th of a second) each box in the grid on the display represents.

By way of example, for a 440Hz “concert A” sine wave, there will be 440 repeats of the basic wave each second. That means the time between each peak is 1/440 seconds each or just over 2mS each.

Perform the following:

- Try to set the pitch to close to 440Hz.
- Use the left/right and up/down buttons to select 2mS as the timebase.
- Observe how each wave pattern is close to being a single box wide.
- Experiment with different timebase settings and see how the display changes.

### 4. Oscilloscope Vertical Scale

Now use the menu to select the left-most yellow oval at the bottom of the display. This is the oscilloscopes “voltage per division” measure and will set the vertical scale. It may often be stated in either “V” or “mV” for volts or milli-volts and indicates the voltage level represented by each box in the grid on the display.

Adjust the VCO1 Amp to full volume (fully clockwise). The top of the waveform should be close to 3.3V and the bottom close to 0V.

- Use the left/right and up/down buttons to select 1V as the V/Div scale.
- Observe how the waveform should now span just over three boxes on the display.
- Adjust the V/Div to 500mV – it is now possible the top of the wave is off the top of the display!
- Use the left/right and up/down buttons to select the small “L” cursor on the far left of the display and move it downwards. This will move the whole display down so that the whole waveform can now be seen.
- Experiment with the VCO1 Amp control to change the level.


Page 6 – Issue 0.1 – Jan 2025 - © diyelectromusic 2025 - https://diyelectromusic.com/2024/05/07/educational-diy-synth-thing/

### 5. Dual Oscillator Oscilloscope and Breadboard

Now connect in the waveform output from VCO2 as well, as shown below.

This patch uses both VCOs with a constant envelope and can be used to explore the waveform from two oscillators running together.

Set the controls on the Synth Thing as follows.

- VCA Volume are fully clockwise.
- VCO1 Amp fully anti-clockwise (off).
- VCO1 and VCO2 Pitch controls to around half-way.
- Use the Sine outputs from both VCOs.
- Watch the oscilloscope as the VCO1 Amp is gradually increased (turn slowly clockwise).
- Now attempt to tune both VCOs to the same pitch.

Press “AUTO” on the oscilloscope and adjust the timebase or V/Div to get a clear display of the waveform. If the detailed information is present, then press and hold “RUN” until it goes away.

Observe the waveform and how it changes as the oscillators are tuned to be closer together.

### 6. Dual Oscillator Oscilloscope – Complex Waveforms

Continuing with the same circuit as the previous experiment, now see what happens to the waveform while doing the following:

- Adjust VCO2 to be just below, almost the same as, and just above VCO1.
- Tune VCO1 and VCO2 to be one octave apart.
- Experiment with different intervals.
- Experiment with different waveforms.

In particular note how two different waveforms, at two different frequencies, are combined in the waveform. See if you can spot the different frequencies “appearing” in the combined waveform.


Page 7 – Issue 0.1 – Jan 2025 - © diyelectromusic 2025 - https://diyelectromusic.com/2024/05/07/educational-diy-synth-thing/

### 7. Oscilloscope and Audio Output

This project shows what is required to connect the oscilloscope to the audio line output.

A professional oscilloscope will usually come with probes to be connected by “BNC” connectors. A cheap hobby oscilloscope such as the DSO152 would typically come with “MCX” connectors, but hobby scopes often come with an adaptor to allow the connection of traditional “BNC” scope probes.

One way to capture the audio output of the Synth Thing is shown above. This uses a 3.5mm stereo to twin mono RCA/phone plug lead with one output going to an amplifier and the other to the oscilloscope (both via more adaptors as necessary).

This patch again uses both VCOs with a constant envelope and can be used to explore the waveform once again.

The difference this time being that we are now seeing the output from the VCA not just the oscillators.

This means that this can be used to show the results of adding in envelopes or additional circuitry, which will be useful in later experiments.

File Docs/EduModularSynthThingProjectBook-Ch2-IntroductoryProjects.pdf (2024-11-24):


Page 1 – Issue 0.1 – Sept 2024 - © diyelectromusic 2024 - https://diyelectromusic.com/2024/05/07/educational-diy-synth-thing/

## The Educational DIY Synth Thing

## Introductory Projects

### Core Kit List

- Educational Synth Thing – ideally with additional “connector” panel (as shown below).
- Pin to Pin Jumper Wires.
- 3.5mm stereo jack (headphone-style) lead.
- Amplification for a line-level signal.
- Optional: 3.5mm to std jack Stereo to Mono converter.
- 7-12V power source: 2.1mm barrel jack – centre positive.

Depending on the amplification used, it might be necessary to convert a 3.5mm stereo (TRS) jack physical connection to a STD (1/4”) mono jack; twin photo jacks; etc.

For power using a 9V battery via a battery clip to 2.1mm barrel jack lead works very well.

### Basic Connections


Page 2 – Issue 0.1 – Sept 2024 - © diyelectromusic 2024 - https://diyelectromusic.com/2024/05/07/educational-diy-synth-thing/

### 1. Basic Oscillator (VCO) Output

This project explores the sounds of the individual oscillators.

Connect the wires as shown.

This provides a fixed HIGH level signal (3V3) to the VCA which means it will always be sounding – there will be no beginning or end to the sound.

The output of VCO1 is fed into the audio input of the VCA so what is heard is the sound of the VCO directly.

Turn up the VCA volume and the VCO1 amplitude then experiment with the VCO1 pitch control.

What are the lowest and highest sounds it can produce? How do these compare to the lowest and highest notes on a piano?

### 2. VCO Waveform on an Oscilloscope

In this experiment we hook up an oscilloscope to actually view the waveform created in the first experiment.

The Oscilloscope has two wires to connect to the Synth Thing: a GND wire (black) and a SIGNAL wire (red). The GND

wire has to be connected to one of the GND connections on the Synth Thing and the SIGNAL wire can then be used to probe different connections on the Synth Thing.

All the connection points apart from the VCO/LFO outputs and the power connections have two header connections. This means it is quite easy to add an extra wire to double up the connection. It is particularly convenient when using an oscilloscope as can be seen here, where it is probing the signal that is being sent into the VCA.

The simplest way to use the oscilloscope is to select “AUTO” mode where it will self-set an appropriate scale to show what it is receiving. If it includes a “frequency” measure try to find the lowest and highest frequencies from the VCO.

Try all four waveforms of the VCO. See how they differ in sound and on the oscilloscope display. See what happens on the oscilloscope as the pitch is changed. See what happens when the amplitude is changed.


Page 3 – Issue 0.1 – Sept 2024 - © diyelectromusic 2024 - https://diyelectromusic.com/2024/05/07/educational-diy-synth-thing/

### 3. Dual Oscillator Output

Repeat the first experiment with the second oscillator then try sounding them both at the same time.

Once again connect the wires as shown, again with a constant HIGH signal into the VCA.

This now feeds the outputs of both oscillators into the VCA audio input which performs some rudimentary mixing of the two signals.

The combined sound won’t be as loud as a single oscillator for reasons to do with the electronics that I won’t go into here.

Experiment with changing the pitches. Experiment with mixing different waveforms.

Use the amplitude setting for VCO1 to fade that signal in and out.

Can you get the oscillators to essentially the same pitch with the same waveform (sine wave probably works best)?

Now make one slightly out of tune. If you’re careful you may hear “beats” as the close together pitches react with each other. This is called a detune effect.

Can you get one oscillator to sound exactly one octave above the other? How about two octaves?

Can you find other intervals, for example a third, a fourth, or a fifth?

### 4. LFO Amplitude Modulation

This experiment modulates an oscillator using the low-frequency oscillator (LFO).

This time we’re using a single oscillator again but connecting its control voltage input to the triangle output of the LFO.

With the amplitude setting turned right down, the only amplitude control will come from the LFO. This means the LFO will be turning the volume up and down according to the rate and depth knobs.

Turn the depth knob all the way up and change the rate knob to see what happens.

Then turn the rate knob to something in the middle and experiment with changing the depth knob.

Change to use the saw output of the LFO. How does the sound change?

When one module (the LFO) is controlling another module in the synthesizer (the VCO in this case) this is called
modulation. In this case the LFO is modulating the VCO signal. In musical terms, modulating the amplitude gives a tremolo type effect.


Page 4 – Issue 0.1 – Sept 2024 - © diyelectromusic 2024 - https://diyelectromusic.com/2024/05/07/educational-diy-synth-thing/

### 5. LFO Pitch Modulation

This repeats the previous experiment but this time seeing how the LFO can affect pitch.

Wire the triangle output of the LFO into the pitch CV rather than the amplitude CV and turn the amplitude right back up.

This time, with the depth set to a middle value vary the rate.

Now pick a relatively low rate and vary the depth settings.

Change to the Saw waveform and experiment with the rate and depth settings. See if you can produce a “pew pew” type sound.

Try it will the oscillators Saw or Square wave and you might get a sound typical of 1980s early electronic video games!

Again in musical terms, modulating the pitch gives a vibrato like effect.

Feel free to try connecting both outputs of the LFO to the VCO – one to the pitch and one to the amplitude.

### 6. Dual VCO+LFO Pitch Modulation

This time we’re hooking up the LFO to the pitch CVs for both oscillators at the same time.

Two extra wires are now added to the previous experiment

One to connect the output of VCO2 to the VCA (in addition to VCO1) and one to duplicate the LFO input into both CVs of the VCOs at the same time.

Start with the LFO rate and depth turned fully anti-clockwise -i.e. essentially “off” and tune the two VCOs to an octave.

Now experiment with the LFO depth and rate controls and hear how the LFO is modulating both VCOs at the same time.

For a different type of effect try connecting the Triangle LFO output to VCO1 CV and the Saw LFO output to VCO2 CV.


Page 5 – Issue 0.1 – Sept 2024 - © diyelectromusic 2024 - https://diyelectromusic.com/2024/05/07/educational-diy-synth-thing/

### 7. External Dual VCO Pitch Control

In this experiment we hook up a solderless breadboard for the first time and use an external component to control the Synth Thing.

We’re going to wire up the breadboards GND and power rails to the Synth Things GND and 3V3 supplies (shown in black and orange).

The we’re going to use an external potentiometer to provide a control voltage to both oscillators at the same time. With the wiring shown above the control voltage from the external potentiometer should vary between 0V (fully anti-clockwise) and 3.3V (fully clockwise).

Both oscillators are wired into the VCO, which is still configured for a constant HIGH control voltage. Turn down both pitch controls for each oscillator and turn the amplitude for VCO1 up full.

Now turn the external potentiometer and note what happens to the sound.

Now slightly detune one of the oscillators by adjusting its own control knob a little.

Notice how the detuning “follows” the setting of the external control. This is because the internal control level is added to the external control.

See if you can set one of the VCOs to be exactly one octave above the other and vary the external control. Try it with different intervals – a fifth, a third, something else.

Experiment with using different waveforms for each oscillator and changing the amplitude of VCO1 to fade it in and out.

As a final experiment, bring in the LFO to control VCO1’s amplitude to automatically modulate the signal from VCO1. Remember to turn the amplitude knob right down to let the LFO take over the control of VCO1.


Page 6 – Issue 0.1 – Sept 2024 - © diyelectromusic 2024 - https://diyelectromusic.com/2024/05/07/educational-diy-synth-thing/

### 8. ADSR Envelope Generator – Part 1

Now that we’ve seen how to connect a solderless breadboard, we can use this to include a switch to trigger one of the envelope generators.

Notice that the VCA EG signal is no longer connected to 3V3 – it is now connected to the output of the first envelope generator EG1.

An envelope will shape the sound – giving it a beginning, a middle, and eventually an end. The TRIG input is used to start the shape. The GATE input is used to determine how long the middle should last before starting to end the sound.

In this experiment, they are connected together and controlled by a single button. This works as the TRIG input is an “edge” input – it is only active when it detects a signal going HIGH, but once it is HIGH it no-longer cares. The GATE input is a “level” input – it will be active for as long as the input is HIGH. When the level stops being HIGH the Synth Thing will end the sound.

There are four controls that set how the shape changes during the playing of the sound: Attack (A), Decay (D), Sustain (S), Release (R). The AD and R knobs control how quickly those stages of the sound change. The S knob controls at what level the “sustain” (middle) part of the sound waits.

The diagram below shows the four stages and how they relate to the TRIG (T) and GATE (G) signals.

Set the ADSR knobs roughly as follows:

A – almost fully anti-clockwise.

D – almost fully anti-clockwise.

S – fully clockwise.

R – in the middle.

Ensure the VCO1 and VCA
volume are turned up and press the button.

Try a short press and a long press and see how the sound changes.


Page 7 – Issue 0.1 – Sept 2024 - © diyelectromusic 2024 - https://diyelectromusic.com/2024/05/07/educational-diy-synth-thing/

### 9. ADSR Envelope Generator – Part 2

Continuing from part 1, the following experiments show different envelopes. Use the ADSR controls to set something that closely matches the diagram and listen to how the sound changes.

Strong Attack, Long Release

The A and D are very short (hard anti-clockwise), meaning the sound will rise and drop to the S level pretty quickly giving quite a “hard” start to the sound.

S is fairly high (clockwise) so the sound will keep sounding whilst the button is pressed.

When the button is released, the sound will die away slowly due to the long R time (clockwise).

Slow Attack, Quick Release

A is set very long (clockwise), meaning that the sound will take a while to arrive.

Once at full volume will quickly settle to the S level, which is pretty high (clockwise) once again.

This will create a characteristic “mwha” type of effect for the sound popular in certain synthesizer music.

When the button is released the sound will die fairly quickly due to the short R time (anti-clockwise).

Short Attack, Immediate Decay

This sound will only sound for a very short length of time, no matter how long the button is pressed.

This is due to the almost zero S level and quick A and D times (all anti-clockwise). The setting of R is largely irrelevant as the sound will have already dropped to nothing before the button is released.

This is the type of envelope that might be wanted for a very percussive sound.

Other ADSR Experiments

With the different envelopes above, investigate what happens for:

- A short press of the button.
- A long press of the button.
- Repeatedly pressing the button slowly.
- Repeatedly pressing the button quickly.


Page 8 – Issue 0.1 – Sept 2024 - © diyelectromusic 2024 - https://diyelectromusic.com/2024/05/07/educational-diy-synth-thing/

### 10.ADSR Envelope Generator for Pitch

The EGs provide a control voltage (CV) that can also be used to control the pitch of an oscillator.

The VCA amplitude has been set back to a constant HIGH level (connected to the 3V3 output) and now the output of EG1 is connected to the VCO1 pitch CV.

With the VCA and VCO1 amplitudes turned up, find a nice “middle” pitch for VCO1.

Set the A and D fairly short (anti-clockwise), set the S level somewhere in the middle, and set the R time fairly short too. Now press the button.

Experiment with both different A,D and R settings and experiment with different S levels.

### 11.ADSR Envelope Generator for Amplitude and Pitch

This now uses both EGs, one to control amplitude and one to control pitch.

In this experiment the button is still triggering EG1 as before, but it also now triggers EG2 as all the GATE and TRIG signals are connected together.

EG1 is once again controlling the amplitude of the VCA but now EG2 has been connected to the pitch CV input of VCO1.

Reset ADSR for both EGs as for the first EG experiment: short A and D, high S and long R.

Turn up the volume of the VCA and VCO1 and set the pitch to somewhere in the middle.

Now press the button and experiment with the different ADSR settings for both EG1 (amplitude) and EG2 (pitch).

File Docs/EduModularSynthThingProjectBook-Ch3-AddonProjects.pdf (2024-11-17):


Page 1 – Issue 0.1 – Sept 2024 - © diyelectromusic 2024 - https://diyelectromusic.com/2024/05/07/educational-diy-synth-thing/

## The Educational DIY Synth Thing

## Optional Add-on Device Projects

### Introduction

This carries on from the previous chapters and assumes that one has a working Synth Thing and has worked through all of the starter projects.

There are three sections in this chapter covering the following:

- The optional add-on touch Keyboard.
- The optional add-on “baby 8” style step sequencer.
- MIDI

In each case once again amplification and power are required as described previously.

### The Add-on Devices

The Touch Keyboard (left) and Baby-8 Sequencer (right).

Reference Details:

- https://diyelectromusic.com/2024/07/14/educational-diy-synth-thing-part-7/
- https://diyelectromusic.com/2024/09/01/baby8-cv-step-sequencer-part-4-in-use/


Page 2 – Issue 0.1 – Sept 2024 - © diyelectromusic 2024 - https://diyelectromusic.com/2024/05/07/educational-diy-synth-thing/

## Touch Keyboard

### Basic connections and setup

Equipment required:

- Synth Thing with power and audio output.
- Touch Keyboard.
- 4-way ribbon cable with JST PH to JST PH connectors (see photo).

The cable connectors are “keyed” and can only be inserted in a particular orientation as shown above.

With the Synth Thing powered off, the keyboard can be connected as shown below.

Points to note:

- The Keyboard gets its power from the Synth Thing, so no further connections are required.
- As the Keyboard works by capacitive touch, it will work better if the person using it also touches the exposed connector at the rear.
- One option is to hold the keyboard with one hand touching the read connector and play it with the other.

The following projects in this section assume keyboard is connected.


Page 3 – Issue 0.1 – Sept 2024 - © diyelectromusic 2024 - https://diyelectromusic.com/2024/05/07/educational-diy-synth-thing/

### 1. Basic Oscillator (VCO) Output

This project revisits the sounds of the individual oscillators.

Connect the wires as shown.

Recall that this provides a fixed HIGH level signal (3V3) to the VCA which means it will always be sounding – there will be no beginning or end to the sound.

Once again the output of VCO1 is fed into the audio input of the VCA so what is heard is the sound of the VCO directly.

Turn up the VCA volume and the VCO1 amplitude. Turn down the VCO1 pitch control.

Play some notes using the keyboard.

Experiment changing the VCO1 pitch control whilst playing notes from the keyboard.

Experiment with different VCO waveforms.

### 2. Dual Oscillator Output

Repeat the first experiment with the second oscillator then try sounding them both at the same time.

Once again connect the wires as shown, again with a constant HIGH signal into the VCA.

This now feeds the outputs of both oscillators into the VCA audio input which performs some rudimentary mixing of the two signals.

Start with both pitch controls turned right down and play some notes on the keyboard.

Experiment with changing the pitches. Experiment with mixing different waveforms.

Use the amplitude setting for VCO1 to fade that signal in and out.

Experiment with the following whilst playing:

- Detuning one of the VCOs.
- Try to get one VCO exactly one octave above the other.
- Try other intervals: a fifth, a third, something else.
- Using different waveforms for the two VCOs.


Page 4 – Issue 0.1 – Sept 2024 - © diyelectromusic 2024 - https://diyelectromusic.com/2024/05/07/educational-diy-synth-thing/

### 3. ADSR Envelope Generator

The keyboard will automatically trigger both envelope generators, so to use them, we just need to patch one of them into the VCA.

Notice that the VCA EG signal is no longer connected to 3V3 – it is now connected to the output of the first envelope generator EG1.

Also notice that unlike the projects in the first set of experiments, we don’t need a wire to trigger the EG. It is done automatically from the keyboard.

Set the ADSR knobs roughly as follows:

A – almost fully anti-clockwise.
D – almost fully anti-clockwise.
S – fully clockwise.
R – in the middle.

Ensure the VCO1 and VCA volume are turned up and play some notes on the keyboard.

Experiment with the ADSR settings.

### 4. ADSR Envelope Generator for Pitch

Repatching the VCA to the 3V3 line, we can now patch EG 1 to control the pitch of VCO1.

It is recommended that the Pitch control is turned right down and that the Sustain level is set fairly low.

Play some notes on the keyboard.

Experiment with different ADSR settings.

See what happens when the Pitch control is used as well.


Page 5 – Issue 0.1 – Sept 2024 - © diyelectromusic 2024 - https://diyelectromusic.com/2024/05/07/educational-diy-synth-thing/

### 5. ADSR Envelope Generator – Dual Pitch Control

This repeats the previous experiment but now both VCOs are patched in and each EG is wired to control a VCO each.

Start with both Pitch controls turned right down and a fairly low sustain level on each EG.

Play some notes on the keyboard.

Experiment with different ADSR settings.

Experiment with detuning one of the VCOs.

Experiment with setting the VCOs to an octave.

Experiment with different waveforms.

### 6. Include the LFO

Now we add in the LFO.

Recall that to use the LFO to control the amplitude of VCO1 the Amp setting must be turned right down.

Start with the ADSR S setting pretty low once again or possibly optionally start with the EGs disconnected from the VCOs..

Experiment with all of the controls:

- LFO Rate and Depth.
- LFO waveforms.
- ADSR for both EGs.
- VCO pitch controls.
- VCO waveforms.


Page 6 – Issue 0.1 – Sept 2024 - © diyelectromusic 2024 - https://diyelectromusic.com/2024/05/07/educational-diy-synth-thing/

### 7. Final Keyboard Patch

This final patch suggests a base from which new patches might be created.

The initially suggested patch does the following:

- EG1 controls the VCA to shape the overall volume of each note.
- The LFO controls both patch and amplitude for VCO1.
- EG2 controls the pitch of VCO2.

Play some notes on the keyboard and experiment with all the settings:

- Rate and Depth for the LFO.
- Swap or remove the links between the LFO and VCO1.
- Try different waveforms for the VCOs.
- Experiment with EG1 ADSR settings to change the overall shape of the sound.
- Experiment with EG2 ADSR settings to change how VCO2 is added to the sound.

## Baby-8 Sequencer


Page 7 – Issue 0.1 – Sept 2024 - © diyelectromusic 2024 - https://diyelectromusic.com/2024/05/07/educational-diy-synth-thing/

### Basic connections and setup

Equipment required:

- Synth Thing with power and audio output.
- Baby-8 Sequencer.
- Jumper wires.

The basic connection is shown below. Note that the Baby 8 is powered from the 3V3 connection of the Synth Thing.

There are three outputs from the Baby 8 as shown in the detail below:

From top to bottom, the connections are:

- GND and (3V3) Power INPUT
- TRIGGER OUTPUT
- GATE OUTPUT
- CV (Control Voltage) OUTPUT


Page 8 – Issue 0.1 – Sept 2024 - © diyelectromusic 2024 - https://diyelectromusic.com/2024/05/07/educational-diy-synth-thing/

### Baby 8 Basic Use

With the connections as shown overleaf, this will explore the basic operation of the Baby 8.

Key principle of operation:

- The Baby 8 will provide pitch CV and GATE/TRIGGER signals to the Synth Thing.
- The Synth Thing will provide power to the Baby 8.

The following highlights the main controls for the Baby 8.

Number of Steps

- This determines how many steps will be played in the sequence. Up to 8 steps can be included, which corresponds to the knob be turned fully clock-wise.

Tempo

- The speed of the sequence is set using the tempo potentiometer. Turning clockwise increases the tempo.

Mute Switches

- Each step can be individually muted (or skipped). Note, this only prevents the GATE/TRIGGER output triggering - the CV will still be set to the pitch according to the position of the corresponding knob.

Run/Stop

- This can be used to pause the sequence.

Step Pitch Controls

- There are 8 potentiometers around the edge of the Baby 8. These are used to set the pitch of the corresponding step. Turning clockwise increases the pitch. Each step has a corresponding LED.


Page 9 – Issue 0.1 – Sept 2024 - © diyelectromusic 2024 - https://diyelectromusic.com/2024/05/07/educational-diy-synth-thing/

### 1. Simple Pitch Sequence

This explores the most basic use of the Baby 8 – controlling the pitch of a VCO.

As with all these projects, the Baby 8 is powered from 3V3 and GND from the Synth Thing.

Only the connection points of the Baby 8 are shown.

The VCA has a constant HIGH level, so is always on and the VCO1 Sine OUTPUT is connected to the VCA’s audio input.

Set up the Synth Thing as follows:

- VCO1 Pitch control turned right down (anti-clockwise).
- VCO1 Amp control turned right up (clockwise).
- VCA Volume control turned right up (clockwise).

On the Baby 8 turn the Steps Switch fully clockwise to run through all 8 steps.

Ensure the Run/Stop switch of the Baby 8 is in the RUN position (to the right).

Experiment changing the Tempo switch and the 8 pitch controls for the different steps.

Change the number of steps using the rotary switch.

Note that the mute switches do not function when the TRIGGER/GATE outputs are not in use.

### 2. Dual Pitch Sequence

This repeats the first experiment but adds in the second VCO.

Two additional connections are required:

- Passing the Baby 8 CV onto VCO2.
- Sending VCO2 to the VCA.

Start with the Pitch controls turned right down on both VCOs (fully anti-clockwise).

Create a sequence on the Baby 8.

Slowly detune VCO2.

Experiment with different settings for the VCO Pitch controls.

Try the different waveforms.


Page 10 – Issue 0.1 – Sept 2024 - © diyelectromusic 2024 - https://diyelectromusic.com/2024/05/07/educational-diy-synth-thing/

### 3. Baby 8 Trigger

To initially explore how the Baby 8 can TRIGGER the Synth Thing, first wire up the TRIGGER OUTPUT as shown below.

The Baby 8 GATE OUTPUT is a continuous signal whenever a step is playing, but the TRIGGER OUTPUT is a shorter pulse.

To see how the Baby 8 can both start and stop notes with the Synth Thing, we’re using the TRIGGER OUPUT connected to both the GATE and TRIGGER INPUT. This means that the Envelope Generator will have time to both start and stop the envelope for each individual step.

Set the ADSR for a short A, short D, high S and reasonably short R.

Turn VCO1 Pitch right down and VCO1 Amp right up.

Create an 8-step sequence on the Baby 8 and turn the tempo down for a slow sequence.

Experiment with the effect of the ADSR settings on the playing sequence.

Notice how a quicker tempo will make it more difficult to complete the complete ADSR envelope if the settings are too long. In particular a long A or R stage will start to eventually overlap with the next step in the sequence.

Try muting some of the steps and see how that affects the playing sequence.

### 4. Baby 8 Trigger and Gate

Finally connect both TRIGGER and GATE to the Synth Thing.

The basic operation will be quite similar to the previous experiment, but without the GATE ever releasing between the steps of the Baby 8, the Envelope Generator will never start its Release phase.

This makes the interaction somewhat complex.

Once again start with a short A, D and R and a slow tempo.

Experiment with muting some of the steps, starting with muting steps 2, 4, 6 and 8, effectively making the Baby 8 a 4-step sequencer with gaps.

See how the ADSR reacts to the GATE signal coming and going as steps are muted.

Whilst a TRIGGER and GATE are provided by the Baby 8, when being used with the Synth Thing, really using the GATE signal is probably not as useful as only using the TRIGGER, except for some quite specialised cases. For further experimentation it is recommended that only the TRIGGER is used.


Page 11 – Issue 0.1 – Sept 2024 - © diyelectromusic 2024 - https://diyelectromusic.com/2024/05/07/educational-diy-synth-thing/

## MIDI

The Synth Thing supports a TRS (“Type A”) MIDI INPUT jack. In fact the Touch Keyboard described earlier is actually a MIDI keyboard and is using MIDI to control the Synth Thing.

To use with a traditional 5-pin MIDI device will require a MIDI DIN to TRS Type A converter cable.

The basic connectivity for MIDI is as follows:

The Synth Thing will respond to MIDI Channel 1. This cannot be changed without reprograming the device.

### A Basic MIDI Patch

The following basic patch can be used to demonstrate basic MIDI operation.

As with the keyboard examples, MIDI will automatically generate internal Pitch CVs for both VCOs, and GATE and TRIGGER signals for both EGs.

A key feature of the MIDI INPUT is that the full pitch range of MIDI notes becomes possible for the Synth Thing. Far more than is available via the Pitch CV input.

All of the keyboard projects can now be repeated with MIDI.

In particular, experiment with:

- Using both VCOs.
- Using both EGs.
- Adding in the LFO.

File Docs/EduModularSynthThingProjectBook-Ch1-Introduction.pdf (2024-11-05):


Page 1 – Issue 0.1 – Sept 2024 - © diyelectromusic 2024 - https://diyelectromusic.com/2024/05/07/educational-diy-synth-thing/

## The Educational DIY Synth Thing

## Introduction to the Synth Thing

This Synth Thing has been designed to provide an “all-in-one” box that can be used to explore the core principles of subtractive analog synthesis. It is designed to be relatively easily linked up to solderless breadboards to allow further experimentation with new circuits.

There are many educational analog synthesizers available, but the key aims of this project are as follows:

- Open Source.
- Can be ”DIY” built relatively cheaply in terms of components¹
- Lo-Fi but good enough to explore the concepts.
- Has real knobs and pluggable wires.
- The wires are “real signals” that can be monitored with an oscilloscope.
- Low voltage.
- MIDI IN compatible.
- Expandable.

Further details of the design and build process can be found here:

https://diyelectromusic.com/2024/05/07/educational-diy-synth-thing/

1 The prototypes were built for a cost of around £50 for a single unit, but four units can probably be built for around £100 due to minimum buys and bulk discounts on components. The real cost of course is the time required to build and 3D print each unit.


Page 2 – Issue 0.1 – Sept 2024 - © diyelectromusic 2024 - https://diyelectromusic.com/2024/05/07/educational-diy-synth-thing/

## Introduction to Analog Synthesis

The Synth Thing is based on a common architecture for an analog synthesizer for subtractive synthesis as follows:

The bottom row of boxes shows some common sources of the different types of signals in an analog synthesizer.

There are many tutorials available online for the core principles of analog synthesis, but the key concepts relevant to the Synth Thing are:

Control Voltages (CV) – most components in an analog synth can be controlled by voltages – be that from a potentiometer (knob), a music keyboard, other synthesizer, sequencer, or whatever. These can be constant (e.g. representing the pitch of a single note), slowly varying (e.g. a vibrato effect), with a specific shape (e.g. defining an envelope or shape for a sound), or quickly changing (e.g. as a modulating signal).

Some modules create control voltages e.g. a low-frequency oscillator (LFO) or envelope generator (EG) and many receive them e.g. a volage controlled oscillator (VCO), filter (VCF) or amplifier (VCA).

Gates and Triggers – control voltages represent continuously varying control whereas gates and triggers define start and stop end points for sounds – e.g. starts of notes and ends of notes.

An audio path shows how an audio signal passes from one module to another to eventually be mixed into a final audible signal.

A audio path would typically define a single playable note – a monophonic (“one sound”) synthesizer.

To play several notes at the same time, e.g. in a chord, requires a polyphonic synthesizer and several parallel audio paths. Or at least parallel oscillators that then share the same audio path once mixed together.

In an analog synthesizer almost any signal could be made into a control voltage, trigger or gate, even audio signals, using suitable electronics.

Typically an analog synthesizer will consist of combinations of oscillators, filters, amplifiers, mixers, sound sources, controllers and a variety of other more specialised modules to create a typically unique type of complex sound.


Page 3 – Issue 0.1 – Sept 2024 - © diyelectromusic 2024 - https://diyelectromusic.com/2024/05/07/educational-diy-synth-thing/

There are several common waveforms that can be generated by an oscillator in an analog synthesizer.

Here are some of the common ones:

Sine | Triangle | Saw | Square

It should be noted that all the waveforms are in physical reality combinations of sine waves built up from the harmonics of a fundamental (base) frequency. In fact, in additive synthesis this is exactly how complex waveforms are generated – by adding together sine waves of different frequencies.

The Synth Thing is designed for subtractive synthesis. It starts with a complex waveform and will eventually use filters to “subtract” elements of the waveform to create interesting sounds.

## The Synth Thing

The Synth Thing provides two voltage-controlled oscillators (VCO1 and VCO2), a low-frequency oscillator (LFO), a voltage-controlled amplifier (VCA) and two four-stage (ADSR) envelope generators (EG1 and EG2) as shown below.

There are no built-in filter stages.

All inputs, and the two EG outputs, have two pin headers. Generally this isn’t for mixing signals, it is to make it easy to monitor input signals using an oscilloscope or to duplicate inputs to other modules. The one exception is the input to the VCA which can act as a simple passive mixer for
| | both VCOs if required.

Both oscillators produce sine, saw, triangle and square wave outputs a the same time.

There are 3V3 and 5V power headers for linking out to solderless breadboards and other circuits.

IMPORTANT: If either of the 3V3 or 5V signals are connected directly to the GND signals then that will short out the Synth Thing and could damage some of the components.

### Basic Signal Properties

- Control voltages (CV) are in the range 0 to 3.3V.
- Gates and Triggers will be either 0V (off) or 3.3V (on).
- Audio signals are in the range 0 to 3.3V, centred on 1.7V (i.e. they are DC biased).
- The VCO CVs will accept varying control voltage signals up to around 500Hz, so are fine when used with a low-frequency oscillator, but are not fast enough for frequency modulation between oscillators.
- All CV, gate and trigger signals have a degree of protection so can accept (but will cut off) signals up to 5V. They will probably cope with higher (e.g. “Eurorack” signal levels), but this is not recommended.
- A pitch CV of 0V is internally mapped onto frequency 65.406Hz which is equivalent to MIDI note C2.
- Pitch CVs use the 1V/oct system, so there is a coverage of just over 3 octaves via CV input.


Page 4 – Issue 0.1 – Sept 2024 - © diyelectromusic 2024 - https://diyelectromusic.com/2024/05/07/educational-diy-synth-thing/

### MIDI Support

The Synth Thing will respond to (monophonic) MIDI Note On and Note Off messages.

A trigger is generated on reception of a Note On message and the gate will be set HIGH. It will remain HIGH until the corresponding Note Off message is received. The pitch is determined by the note value in the Note On message.

Whist the control voltages are internally mapped so that 0V corresponds to MIDI note C2, when driven over MIDI the Synth Thing will actually respond to any MIDI note from 0 through to 127 (G9) although practically any produced notes are limited by the performance of the hardware to around B8 due to the sample rates used.

MIDI will also set both VCOs to the same pitch, but the control knobs can be used to add to the pitch to detune them further.

When using the additional connections panel there are two options for MIDI: either use a TRS (“Type A” wiring) MIDI jack or the custom JST header connection:

Note: It is important that only one MIDI connection is plugged in at any one time.

Details of how to use the custom JST header can be found here: https://diyelectromusic.com/2024/07/14/educational-diy-synth-thing-part-7/

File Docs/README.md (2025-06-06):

# ESP32EduModHackThing Documentation

## Getting Started

* One-sheet Getting Started Guide: [Download Here](EduModSynthThing-GettingStarted.pdf).
* Some first experiments: https://diyelectromusic.com/2024/06/17/educational-diy-synth-thing-part-5/

## Tutorials

Summary project slides:
* [Introduction, First Projects, Add-ons](EduModularSynthThingProjects-Slides.pdf)
* [Curated Selection of the above as a "workbook"](EduModularSynthThingProjectSelection.pdf)

Detailed notes:
* [Chapter 1: Introduction](EduModularSynthThingProjectBook-Ch1-Introduction.pdf)
* [Chapter 2: Introductory Projects](EduModularSynthThingProjectBook-Ch2-IntroductoryProjects.pdf)
* [Chapter 3: Optional Add-ons](EduModularSynthThingProjectBook-Ch3-AddonProjects.pdf)
* [Chapter 4: Oscilloscope](EduModularSynthThingProjectBook-Ch4-Oscilloscope.pdf)
* [Chapter 5: External Passive Circuits](EduModularSynthThingProjectBook-Ch5-ExternalPassiveCircuits.pdf)
* [Chapter 6: External Active Circuits](EduModularSynthThingProjectBook-Ch6-ExternalActiveCircuits.pdf)

## License, Use, Feedback, Contributions

Released under a MIT license.  No fitness for any purpose suggested or implied.  Use at your own risk.  I am not an electronics person - I'm just messing around.

**Do not plug this into anything else and certainly not anything expensive or wanted.**

Contributions are not being accepted.  This is just a repository for the design, but suggestions and conversations about it welcome on my blog or via social media.

Kevin

_All code and designs Copyright (c) Kevin (diyelectromusic)_

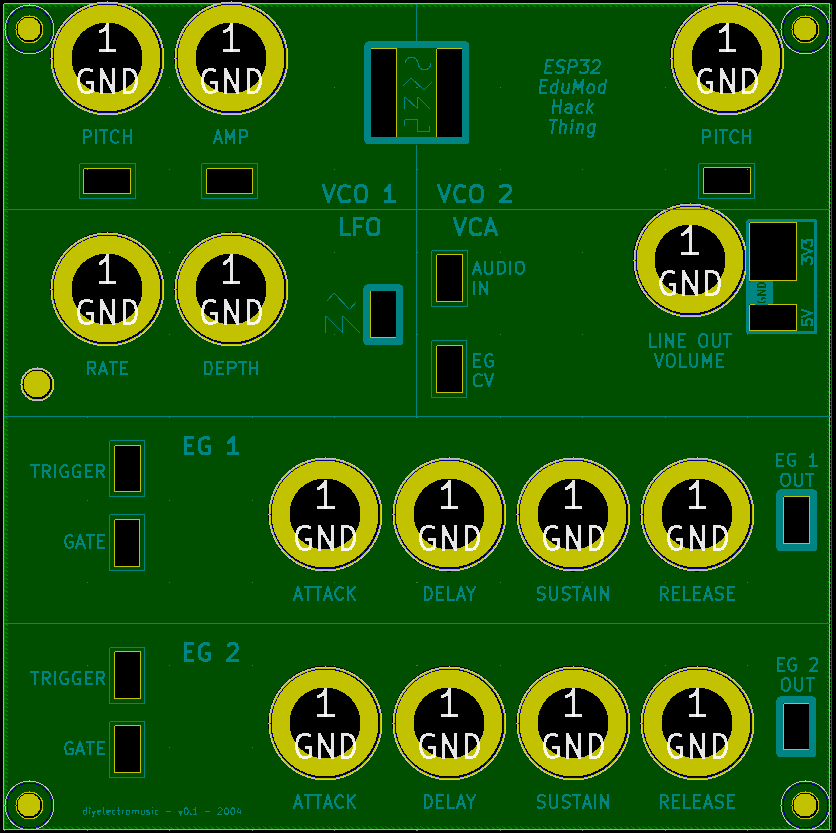
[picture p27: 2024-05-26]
Hardware/ESP32EduModHackThing-panel-pcb.png

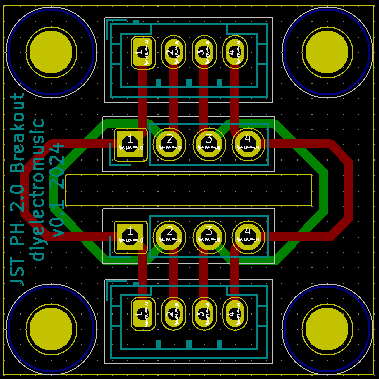
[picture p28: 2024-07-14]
Hardware/JSTSH4pinBreakout.png

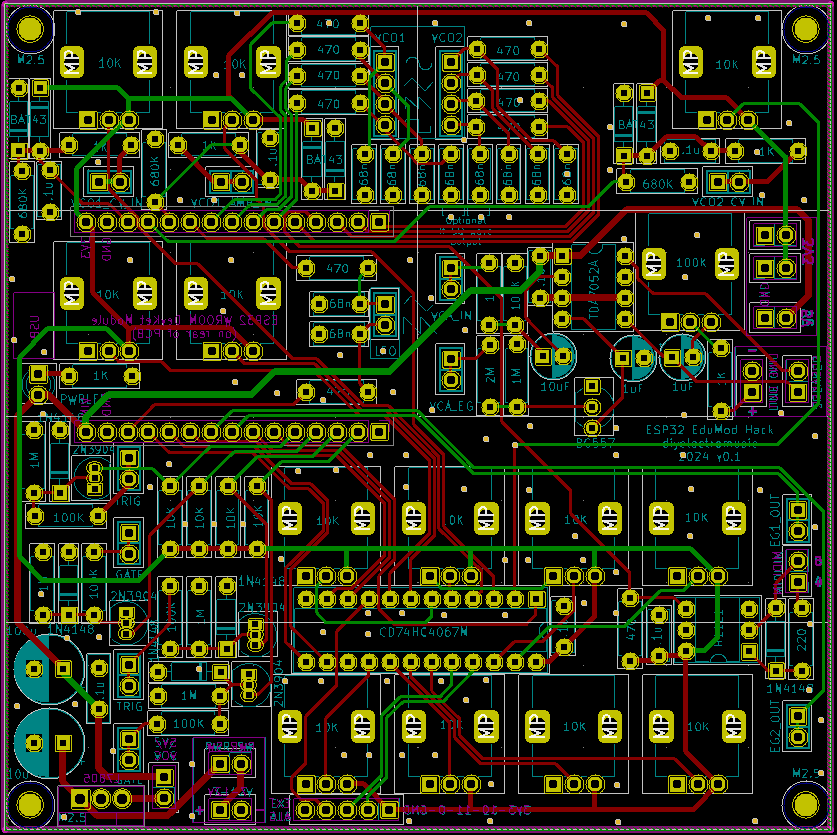
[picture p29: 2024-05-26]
Hardware/ESP32EduModHackThing-pcb.png

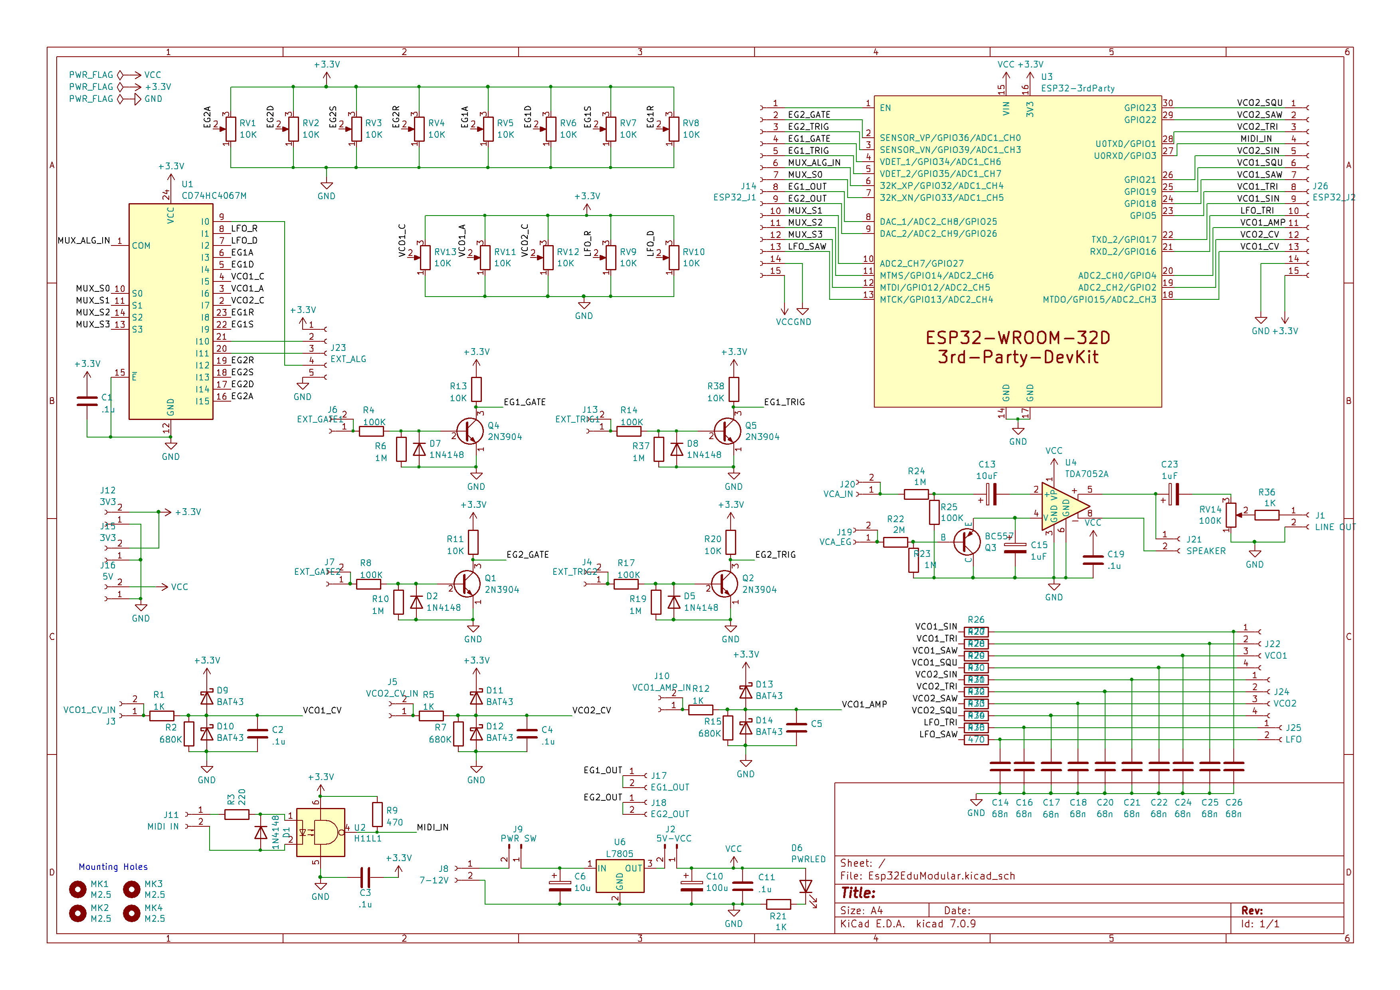
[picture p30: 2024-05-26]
Hardware/ESP32EduModHackThing-sch.png

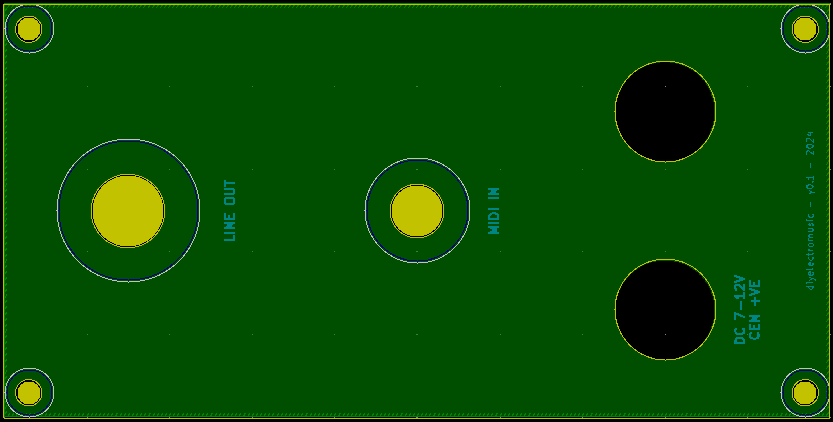
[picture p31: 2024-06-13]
Hardware/ESP32EduModHackThing-Acc-panel-pcb.png

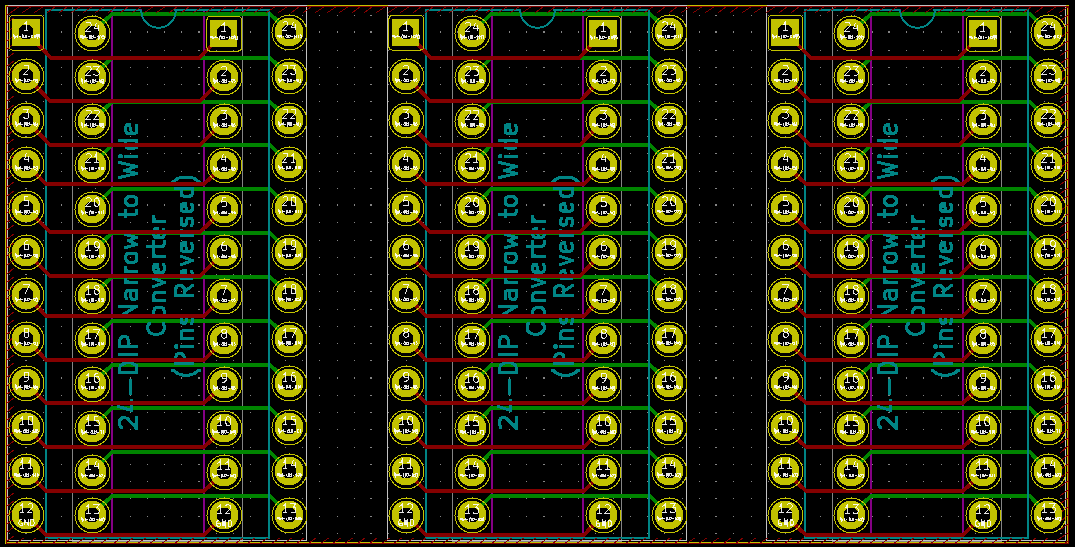
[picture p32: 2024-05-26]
Hardware/DIP24Converter-pcb.png

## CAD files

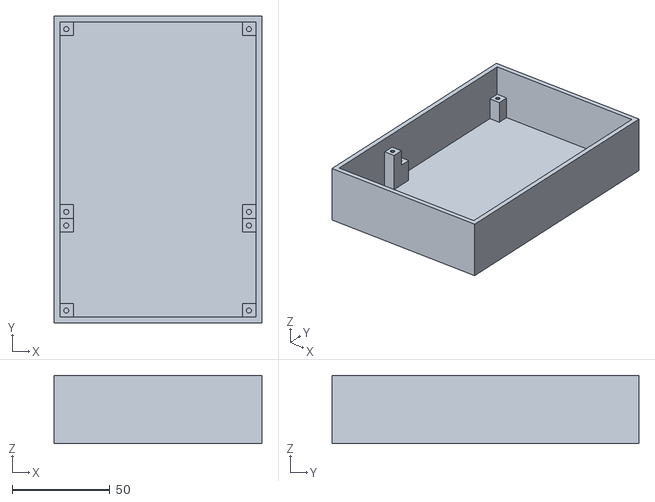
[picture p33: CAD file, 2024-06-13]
Hardware/Enclosure/ModThingBox.stl
106.6 x 157.2 x 35.0

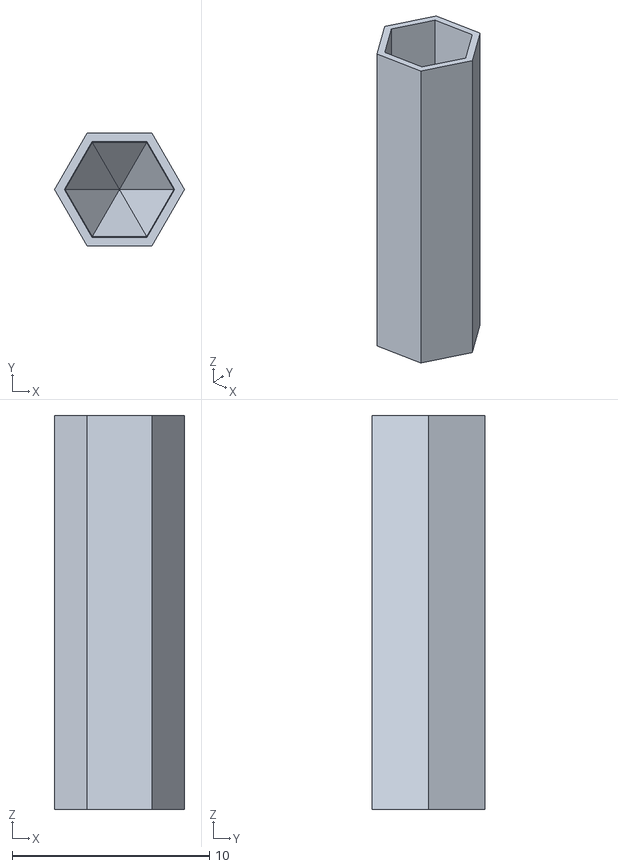
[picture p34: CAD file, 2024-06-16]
Hardware/SpacerTool/HexSpacerSheath.stl
6.60 x 5.72 x 20.0

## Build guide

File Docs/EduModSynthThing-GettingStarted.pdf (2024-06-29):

## Edu Modular Synth Thing Usage Notes

Detailed guidelines and instructions can be found here:

https://diyelectromusic.com/2024/06/17/educational-diy-synth-thing-part-5/

Key points:

- There are no internal, default connections. With no jumper wires, it will not make a sound.
- There is no short-circuit protection. If GND and 3V3 or 5V are connected together Bad Things Might Happen to the synth.
- All internal patch signals are 0-3.3V and either (biased) audio or control signals and gates/triggers.
- The GND and 3V3 connections can be used with a fixed “LOW” or “HIGH” signal is required.
- All inputs have some protection against over and under voltage but it is better to convert any external circuits to 0 to 3.3V.
- The GND/3V3 and GND/5V connections can be used to link to a solderless breadboard or power an external circuit (within limitations).
- The EG outputs are not buffered, so should not be connected to anything likely to draw more than a few mA current.
- The EG Trigger and Gate can be patched together for a combined Gate/Trigger input.

Extra care should be taken when using the GND, 3V3 and 5V power signals.

### Making the First Noise

Kit Required:

- 9V battery, clip and barrel connector.
- External amplification.
- 3.5mm stereo jack lead to connect to amplification.
- Jumper wires

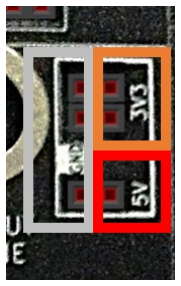
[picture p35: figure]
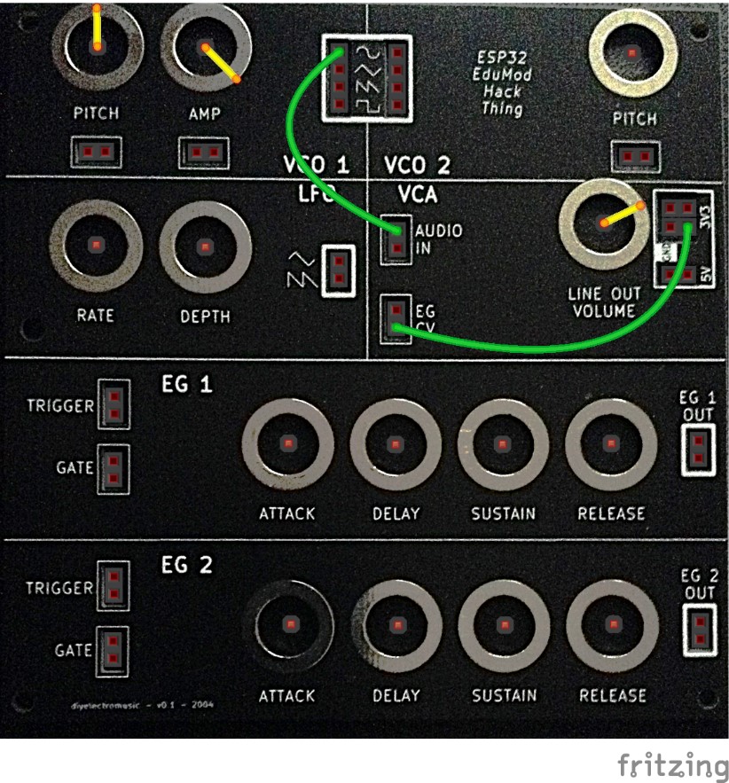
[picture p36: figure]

Note that the 3V3 connector is used as a fixed “HIGH” envelope signal to the VCA.

Both the VCO amplitude and VCA line out volume are turned up.

The VCA gets an audio input direct from the VCO1 output. Any of the four waveforms can be used as the output.

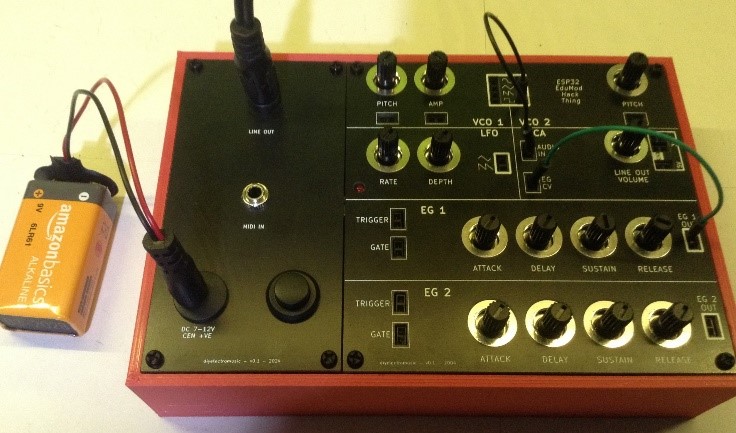
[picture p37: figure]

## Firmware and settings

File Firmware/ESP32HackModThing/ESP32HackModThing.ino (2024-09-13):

/*
  // Simple DIY Electronic Music Projects
  //    diyelectromusic.wordpress.com
  //
  //  ESP32 Modular Hack Thing
  //  https://diyelectromusic.wordpress.com/2024/05/07/educational-diy-synth-thing/
  //
      MIT License

      Copyright (c) 2024 diyelectromusic (Kevin)

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
      THE SOFTWARE IS PROVIDED "AS IS", WITHOUT WARRANTY OF ANY KIND, EXPRESS OR
      IMPLIED, INCLUDING BUT NOT LIMITED TO THE WARRANTIES OF MERCHANTABILITY, FITNESS
      FOR A PARTICULAR PURPOSE AND NONINFRINGEMENT. IN NO EVENT SHALL THE AUTHORS OR
      COPYRIGHT HOLDERS BE LIABLE FOR ANY CLAIM, DAMAGES OR OTHER LIABILITY, WHETHERIN
      AN ACTION OF CONTRACT, TORT OR OTHERWISE, ARISING FROM, OUT OF OR IN CONNECTION
      WITH THE SOFTWARE OR THE USE OR OTHER DEALINGS IN THE SOFTWARE.
*/
#include "task0.h"
#include "task1.h"

//#define S_DEBUG 1
#ifdef S_DEBUG
#warning Make sure GPIO 4 is not used as an oscillator to allow printing
#endif

void core0Entry (void *pvParameters);
TaskHandle_t core0Task;
void core1Entry (void *pvParameters);
TaskHandle_t core1Task;
void core1SubTaskEntry (void *pvParameters);
TaskHandle_t core1SubTask;

void setup () {
#ifdef S_DEBUG
  Serial.begin(115200);
#endif
  delay(300);
  // NB: Need to start MIDI on Task 1 before PWM on Task 0 as TX is reused as a PWM output...
  xTaskCreatePinnedToCore(core1Entry, "Core 1 Task", 2048, NULL, 1, &core1Task, 1);
  // Sub task is higher priority than "main" task and used for period functions
  xTaskCreatePinnedToCore(core1SubTaskEntry, "Core 1 SubTask", 2048, NULL, 2, &core1SubTask, 1);
  delay(300);
  xTaskCreatePinnedToCore(core0Entry, "Core 0 Task", 4096, NULL, 1, &core0Task, 0);
}

void loop () {
  // No main loop here
}

void core0Entry (void *pvParameters) {
  Task0Setup();

  for (;;) {
    Task0Loop();
    vTaskDelay(1); // Allow FreeRTOS IDLE to maintain watchdog
  }
}

void core1Entry (void *pvParameters) {
  Task1Setup();

  for (;;) {
    Task1Loop();
    vTaskDelay(1); // Allow FreeRTOS IDLE to maintain watchdog
  }
}

void core1SubTaskEntry (void *pvParameters) {
  Task1SubTaskSetup();

  // Set up for a period task.
  // Based on example code for xTaskDelayUntil() in ESP32 FreeRTOS IDF reference.
  TickType_t xLastWakeTime;
  const TickType_t xFrequency = pdMS_TO_TICKS(1); // 1mS period (1kHz)
  BaseType_t xWasDelayed;
  xLastWakeTime = xTaskGetTickCount ();

  for (;;) {
    xWasDelayed = xTaskDelayUntil( &xLastWakeTime, xFrequency );
    Task1SubTaskLoop();
  }
}

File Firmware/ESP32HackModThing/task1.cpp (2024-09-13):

#include <Arduino.h>
#include <MIDI.h>
#include "task1.h"
#include "muxalg.h"
#include "fastalg.h"
#include "env.h"
#include "task0.h" // for MIDI frequency handling

//#define DBG_TIMING
//#define DBG_DUMP_ADSR

#ifdef DBG_TIMING
#define DISABLE_DAC
#warning Using Timing pins on 25 and 26
//#define TIMING_PIN1 25
//#define TIMING_PIN1_TOG
#define TIMING_PIN2 26
#define TIMING_PIN2_TOG
#define TIMING_PIN3 25
#endif

//--------------------------
//    MIDI Setup
//--------------------------
MIDI_CREATE_DEFAULT_INSTANCE();
#define MIDI_CHANNEL MIDI_CHANNEL_OMNI

//--------------------------
//    IO Configuration
//--------------------------
#define NUM_DAC_PINS 2  // Also the number of EGs possible
int dac_pins[NUM_DAC_PINS] = {25, 26};
#define NUM_ADC_PINS 4  // Per DAC
// NB: Analog IO is via the MUX
int adc_pins[NUM_DAC_PINS][NUM_ADC_PINS] = {
   3, 4, 9, 8,  // EG 1/ADSR
  15,14,13,12   // EG 2/ADSR
};
uint16_t adcval[NUM_DAC_PINS][NUM_ADC_PINS];

void dacOutput (uint8_t pin, uint8_t value) {
#ifndef DISABLE_DAC
  dacWrite (pin, value);
#endif  
}

#define FAST_ALG_PINS 3
int fastalgmv[FAST_ALG_PINS]   = {true, false, true};  // ReadMilliVolts or not
int fastalgpins[FAST_ALG_PINS] = {15,4,2};

//--------------------------
//    Env Gen Setup
//--------------------------
#define NUM_ENV NUM_DAC_PINS
CEnv *pEnv[NUM_ENV];

int trig_pins[NUM_ENV] = {35,39};
int gate_pins[NUM_ENV] = {34,36};
int lasttrig[NUM_ENV];
int lastgate[NUM_ENV];
bool adsrgate[NUM_ENV];
bool midigate;

void envSetup() {
  for (int i=0; i<NUM_ENV; i++) {
    pEnv[i] = new CEnv();
    lasttrig[i] = HIGH;
    lastgate[i] = HIGH;
    adsrgate[i] = false;
  }
  midigate = false;
}

void envTrigger (void) {
  for (int i=0; i<NUM_ENV; i++) {
    pEnv[i]->triggerADSR();
  }
}

void envGate (void) {
  for (int i=0; i<NUM_ENV; i++) {
    if (midigate || adsrgate[i]) {
      // If either gate is on, then gate is on
      pEnv[i]->gateADSR (true);
    }
    else if (!midigate && !adsrgate[i]) {
      // If both gates are off, then gate is off
      pEnv[i]->gateADSR (false);
    }
  }
}

void envScan (void) {
  // Still not sure of the behaviour on MIDI NoteOff for pitch...
  // Should it reset the frequency directly on receiving NoteOff?
  // But then any envelope Release stage resets to the base pitch too...
  // Or maybe just leave it at the last pitch?
  return;
  
  // Check status of both envelopes and MIDI gate
  // and if both have stopped then reset the midi frequency.
  uint8_t res=0;
  if (!midigate) {
    for (int i=0; i<NUM_ENV; i++) {
      if (pEnv[i]->getADSR () != 0) {
        res = res | (1<<i);
      }
    }
    if (res == 0) {
      // All envelopes complete
      clearMidiFrequency ();
    }
  }
}

//--------------------------
//    IO Loops
//--------------------------
void Task1FastAlgIOLoop (void) {
  for (int i=0; i<FAST_ALG_PINS; i++) {
    FastAlgLoopSingle(fastalgpins[i], fastalgmv[i]);
  }
}

void Task1AlgIOLoop (void) {
  for (unsigned i=0; i<NUM_DAC_PINS; i++) {
    // cycle through each defined potentiometer
    bool setAdsr = false;
    for (unsigned p=0; p<NUM_ADC_PINS; p++) {
        uint16_t algval = MuxAnalogRead(adc_pins[i][p]);
        if (algval != adcval[i][p]) {
          setAdsr = true;
        }
        adcval[i][p] = algval;
    }

    if (setAdsr) {
      pEnv[i]->setADSR(adcval[i][0], adcval[i][1], adcval[i][2], adcval[i][3]);
    }
  }  
}

void Task1DigIOLoop (void) {
  // Check gate/triggers
  for (unsigned i=0; i<NUM_DAC_PINS; i++) {
    // NB: Triggers are active LOW
    int trigval = digitalRead(trig_pins[i]);
    if ((trigval == LOW) && (lasttrig[i] == HIGH)) {
      pEnv[i]->triggerADSR();
    }
    else {
      // No change
    }
    lasttrig[i] = trigval;

    // NB: Gates are active LOW
    int gateval = digitalRead(gate_pins[i]);
    if ((gateval == LOW) && (lastgate[i] == HIGH)) {
      // Gate is ON
      adsrgate[i] = true;
      envGate();
    }
    else if ((gateval == HIGH) && (lastgate[i] == LOW)) {
      // Gate is OFF
      adsrgate[i] = false;
      envGate();
    }
    else {
      // No change
    }
    lastgate[i] = gateval;
#ifdef DBG_DUMP_ADSR
    if (i==0) {
      Serial.print(trigval);
      Serial.print("\t");
      Serial.print(lasttrig[i]);
      Serial.print("\t");
      Serial.print(gateval);
      Serial.print("\t");
      Serial.print(lastgate[i]);
      Serial.print("\t");
      pEnv[i]->dumpADSR();
    }
#endif
  }
}

//--------------------------
//    ESP 32 Timer ISR
//--------------------------

// Timer configuration
// NB: CPU Freq = 80MHz so dividers used to get other
//     frequencies for syncing to other operations.
//
// For a timer frequency of 100,000Hz i.e. divider of 800,
// the Timer alarms would be configured in units of 10uS.
//
// I'm after a sample rate of 10kHz, which requires a 100uS
// period, so I'm going to trigger an alarm every 10 'ticks'.
//
#define SAMPLE_RATE_KHZ 10  // 10kHz (0.1mS)
#define TIMER_FREQ  100000  // 100kHz (0.01mS)
#define TIMER_RATE  10      // 0.1mS

// Use the ESP32 timer routines
hw_timer_t *Task1Timer = NULL;

int toggle1;
uint8_t sample[NUM_DAC_PINS];
void ARDUINO_ISR_ATTR Task1TimerIsr (void) {
#ifdef TIMING_PIN1
#ifdef TIMING_PIN1_TOG
  if (toggle1) {
    digitalWrite(TIMING_PIN1, HIGH);
  } else {
    digitalWrite(TIMING_PIN1, LOW);
  }
#else
  digitalWrite(TIMING_PIN1, HIGH);
#endif
#endif
  toggle1 = !toggle1;

  // Write out last value first to remove
  // any jitter from the timing of the ISR.
  for (unsigned i=0; i<NUM_DAC_PINS; i++) {
    dacOutput(dac_pins[i], sample[i]);
  }
  
  // Then calculate the new samples for next time
  for (unsigned i=0; i<NUM_DAC_PINS; i++) {
    sample[i] = pEnv[i]->nextADSR ();
  }
  
#ifdef TIMING_PIN1
#ifndef TIMING_PIN1_TOG
  digitalWrite(TIMING_PIN1, LOW);
#endif
#endif
}

void Task1TimerSetup () {
  Task1Timer = timerBegin(TIMER_FREQ);
  timerAttachInterrupt(Task1Timer, &Task1TimerIsr);
  timerAlarm(Task1Timer, TIMER_RATE, true, 0);
}

//--------------------------
//    MIDI Handling
//--------------------------
byte playing;
void MidiNoteOff(byte channel, byte pitch, byte velocity) {
  // If we clear the frequency now, then any release stage of the env
  // will instantly switch to the original reference frequency...
  //clearMidiFrequency ();
  if (playing == pitch) {
    // Only turn off the gate if received a matching note off to the
    // currently playing note, otherwise overlapping On/Off events
    // gets very messy.
    midigate = false;
    envGate();
    playing = -1;
  }
}

void MidiNoteOn(byte channel, byte pitch, byte velocity) {
  if (velocity == 0) {
    MidiNoteOff (channel, pitch, velocity);
    return;
  }
  setMidiFrequency (pitch);
  playing = pitch;
  midigate = true;
  envGate();
  envTrigger();
}

void MidiSetup (void) {
  MIDI.begin(MIDI_CHANNEL);
  MIDI.turnThruOff (); // Don't want to spam TX pin as using that for PWM
  MIDI.setHandleNoteOn(MidiNoteOn);
  MIDI.setHandleNoteOff(MidiNoteOff);
}
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

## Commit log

2024-05-19 Upload test code
    Range of sketches for testing the boards.
2024-05-26 Added first version of the PCBs
    Added main PCB, DIP converter, front panel
    [DIP24Converter-B_Cu.gbr, DIP24Converter-B_Mask.gbr, DIP24Converter-B_Silkscreen.gbr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]
2024-06-13 Add connector panel and box
    [Esp32EduModular-Acc-Panel-B_Cu.gbr, Esp32EduModular-Acc-Panel-B_Mask.gbr, Esp32EduModular-Acc-Panel-B_Silkscreen.gbr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]
2024-06-16 Added Hex Spacer tool
    [HexSpacerSheath.stl]
2024-07-14 Added alternative connector panel
    [Esp32EduModular-Acc-Panel+JST-B_Cu.gbr, Esp32EduModular-Acc-Panel+JST-B_Mask.gbr, Esp32EduModular-Acc-Panel+JST-B_Silkscreen.gbr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]
2025-05-09 Added start of Ch 6
    Some first external active circuits
2025-06-06 Latest Active Circuit Ideas
